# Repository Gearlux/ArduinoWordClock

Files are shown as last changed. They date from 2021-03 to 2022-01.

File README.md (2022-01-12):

# NeoWordClock

I started this project when I first saw the [QLockTwo](https://qlocktwo.com/eu/) word clock in a [shop](https://www.lightpoint.be/) while buying the wonderful [Secto Octo 4240](https://www.sectodesign.fi/pendant-lamps/octo-4240-pendant-lamp) lamp.

My girlfriend was also quite impressed, but the price tag kept me from buying the clock. When home, I decided to build a clock myself. Research on the internet led to some kits:
- [Du kansst mitspielen](https://www.du-kannst-mitspielen.com/p/bausatz-303-universal-version-2-3)
- [build-yours.de](https://build-yours.de/product/wordclock-jupiter/)
- [Leuchtbildshop.de](https://www.leuchtbildshop.net/epages/64015097.sf/de_DE/?ObjectPath=Categories)
- [Bastel Laden](https://bastelladen.wortuhr.de/wortuhr-bausatz-42ger-classic.html)

The goal however was to build my own clock. I will try to describe the process here.

The biggest challenge was the electronics. While there are several [DIY](https://en.wikipedia.org/wiki/Do_it_yourself) instructions available
- [Wordclock](https://www.instructables.com/Wordclock/)
- [ArduinoWordClock](https://www.instructables.com/Arduino-Word-Clock/)
this involved a lot of soldering and wires. 

More research led to the [QlockTwo_DIY](https://github.com/jolau/QlockTwo_DIY) github project.
These seemed the most promising project, but I was confused by the schematics



Not knowing anything about Arduino and electronics, I decided to buy the [ELEGOO UNO R3 Super Starter kit](https://www.elegoo.com/collections/uno-r3-starter-kits/products/elegoo-uno-project-super-starter-kit). Not because it was the best, but it was the cheapest kit which was directly available.

With the [Elegoo tuturial](https://www.elegoo.com/blogs/arduino-projects/elegoo-uno-project-super-starter-kit-tutorial), I managed to get myself a little bit familiar with [Arduino](https://www.arduino.cc/) and it's electronics. 
The journey of the word clock can begin ...

- [Tutorials combined ... and more](prototype/prototype.md)
- [User Interface](userinterface/userinterface.md)
- [Settings](settings/settings.md) stored

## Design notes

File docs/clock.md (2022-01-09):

# Clock mode

When you enter the clock mode, "het is" is displayed in red and blue (or starts blinking if you have a prototype).

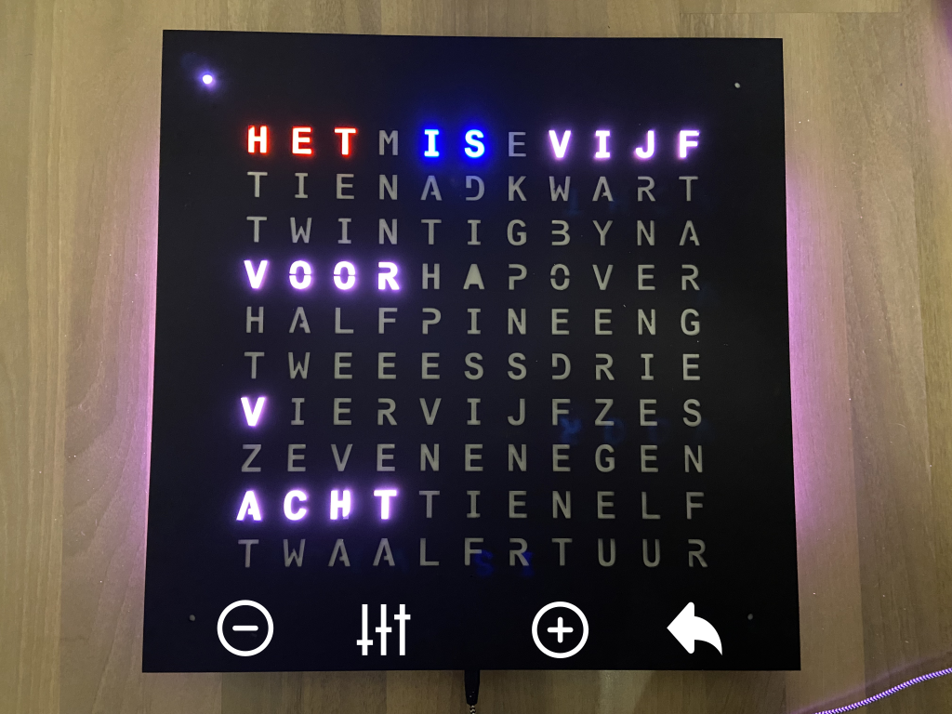
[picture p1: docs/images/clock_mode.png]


Depending on the mode, the hour, the five minutes or the minute dots start blinking.

| | |
| -- | -- |
|  | &bull; Tap to decrease hour/5 minutes/minute dots |
|  | &bull; Tap to cycle through hour/5 minutes/minute dots Auto/High/Low brightness <br/> &bull; Hold to reset seconds |
|  | &bull; Tap to increase hour/5 minutes/minute dots  |
|  | &bull; Hold to return to [main mode](main.md) |

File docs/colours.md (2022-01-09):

# Colour mode

Colour mode looks like this

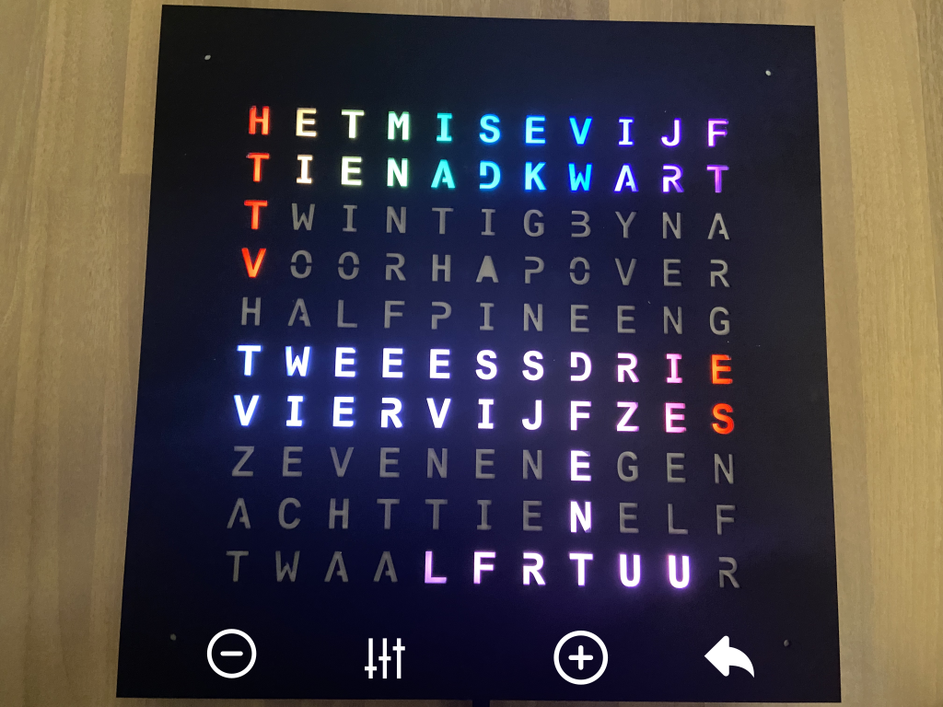
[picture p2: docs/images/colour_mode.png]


You can set the [hue](https://en.wikipedia.org/wiki/Hue) and the [saturation](https://en.wikipedia.org/wiki/HSL_and_HSV) of the leds.
The brightness is controlled in the [brightness mode](brightness.md).

| | |
| -- | -- |
|  | &bull; Tap to decrease hue/saturation |
|  | &bull; Tap to toggle between hue and saturation |
|  | &bull; Tap to increase hue/saturation |
|  | &bull; Hold to return to [main mode](main.md) |

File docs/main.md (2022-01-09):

# Main mode

When booting the clock, all letters will be displayed in rainbow colors. At the bottom of the clock, you find 4 zones to set and configure the clock.

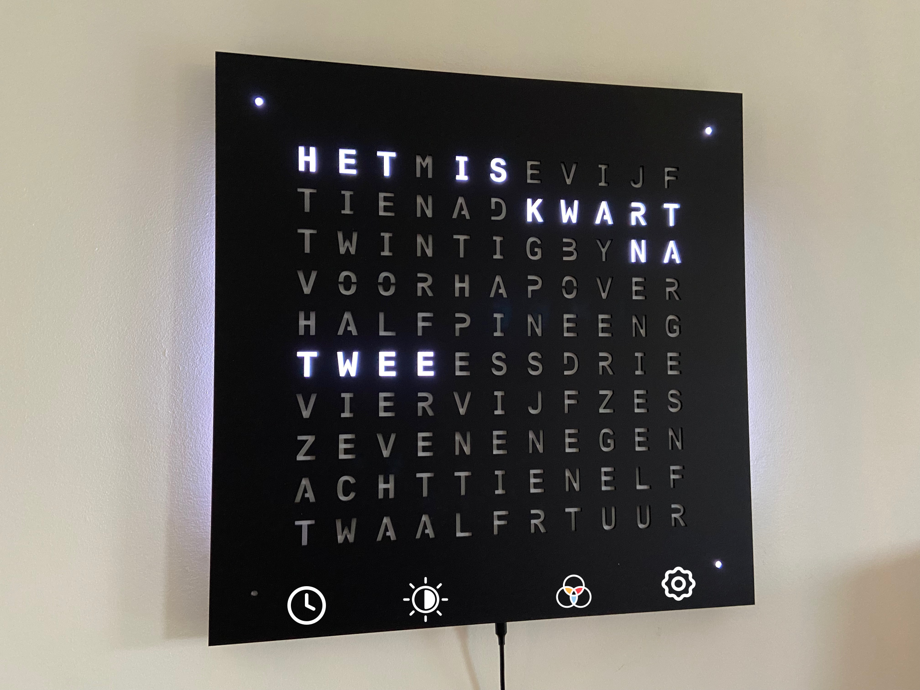
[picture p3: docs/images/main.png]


It is important that you do not touch the capacitive zones at the bottom of the clock when the clock initializes. If the clock behaves weird, unplug the power and repower the clock to reset these capacitive zones.

| | |
| -- | -- |
|  | &bull; Tap to toggle seconds on/off <br/>  &bull; Hold to enter [clock mode](clock.md)  |
|  | &bull; Tap to toggle Auto/High/Low brightness <br/>  &bull; Hold to enter [brightness mode](brightness.md) |
|  | &bull; Tap to cycle colours <br/>  &bull;  Hold to [configure your colour](colours.md)  |
|  | &bull; Tap to see a surprise <br/>  &bull; Hold to [configure the clock](settings.md)  |

## Startup Screen

If you boot the clock, rainbow colors appear

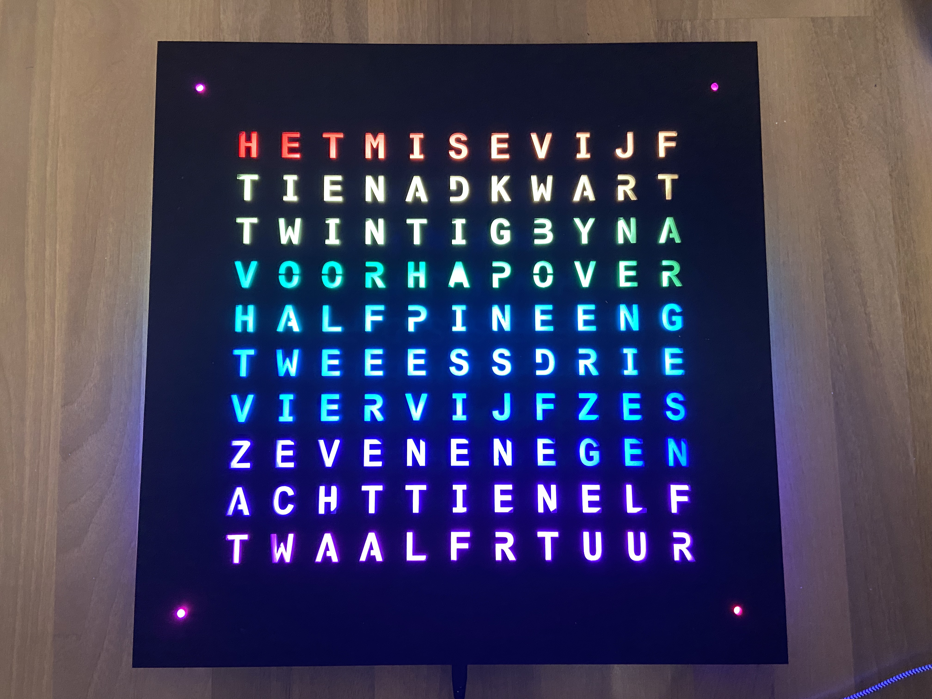
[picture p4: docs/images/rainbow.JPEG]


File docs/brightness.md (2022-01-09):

# Brightness mode

When you enter brightness mode, you see the following screen

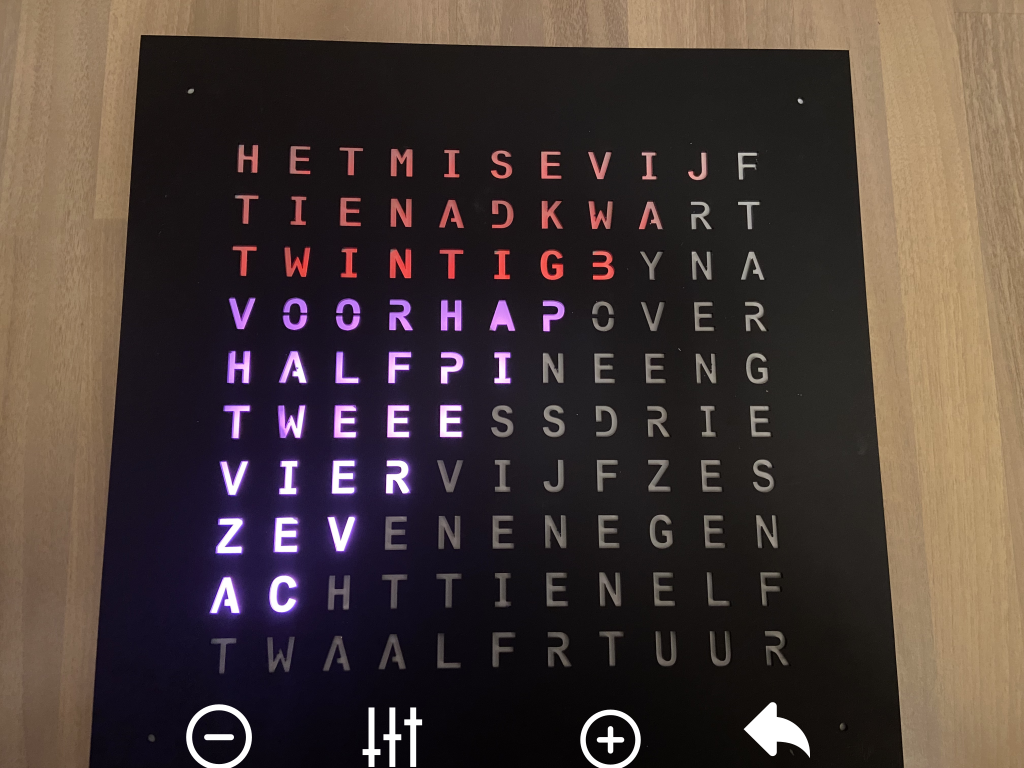
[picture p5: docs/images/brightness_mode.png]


The top row represents the minimum brightness, the bottom row represents the maximum brightness. The active row will blink.

| | |
| -- | -- |
|  | &bull; Tap to decrease minimum/maximum brightness |
|  | &bull; Tap to toggle between minimum and maximum brightness |
|  | &bull; Tap to increase minimum/maximum brightness |
|  | &bull; Hold to return to [main mode](main.md) |

## Automatic brightness

In automatic brightness mode (see [main mode](main.md)) the brightness is determined by the amount of light that is measured by the light sensor next to the power supply.

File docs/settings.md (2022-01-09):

# Settings mode

In settings mode, the clock is temporarily set to 12:20 or 12:40.

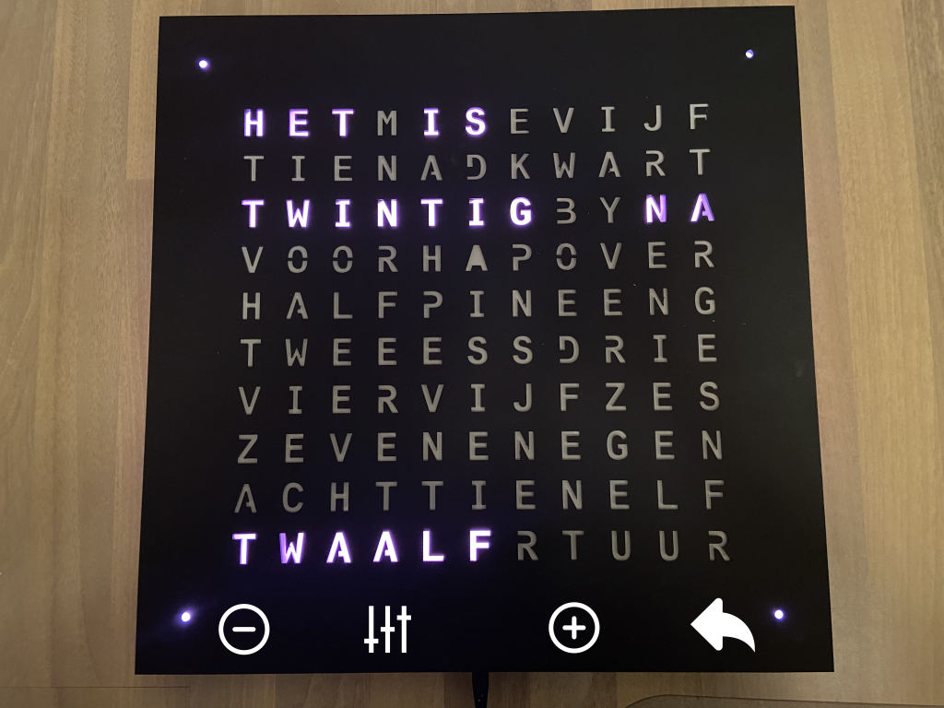
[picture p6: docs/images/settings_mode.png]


| | |
| -- | -- |
|  | &bull; Tap to toggle the display of "Het is" <br/> &bull; Hold to toggle the display of the minute dots |
|  | &bull; Tap to toggle between "over" and "na" <br/> &bull; Hold to toggle between "twintig over/na/voor" and "tien voor/over/na half" |
|  | &bull; Tap to switch the backlight on or off <br/> &bull; Tap to switch between normal or faded transition |
|  | &bull; Hold to return to [main mode](main.md) |

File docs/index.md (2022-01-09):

# NeoWordClock

The 50x50cm NeoWordClock is mounted on the wall like a picture and is currently only available in Dutch.

<center>
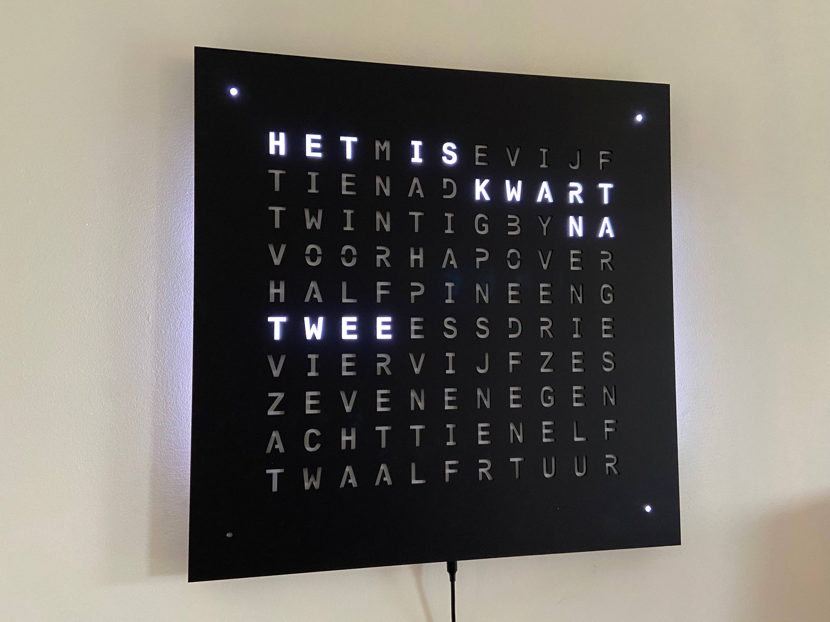
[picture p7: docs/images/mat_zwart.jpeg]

</center>

The dots show the minutes: 'Het is 18 na twee'.

## Unique Features

### Coloured Letters

It is possible to change the colour of the letters and set the mood of the clock.

<center>
<video width="320" height="240" controls autoplay loop>
  <source src="videos/NeoWordClock.mp4" type="video/mp4">
</video>
</center>

### Backlight

The backlight of the clock creates the correct ambiance in your room.

<center>
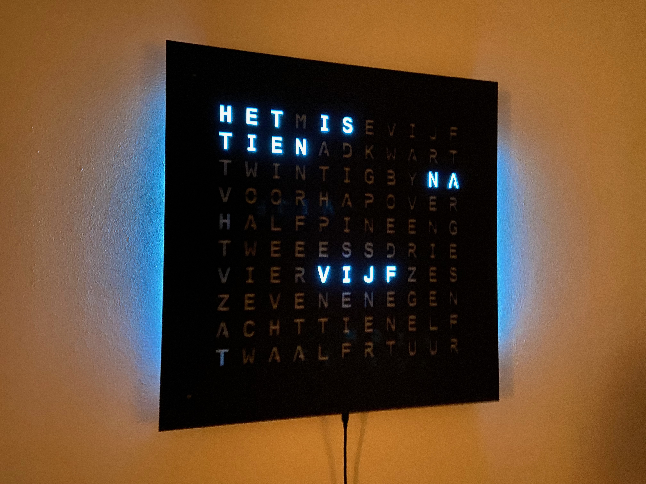
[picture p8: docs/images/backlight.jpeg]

</center>

### Fader

The clock can fade from one hour to another.

<center>
<video width="320" height="240" controls autoplay loop>
  <source src="videos/fading.mp4" type="video/mp4">
</video>
</center>
### Seconds

Seconds can be displayed as a moving letter. This turns the clock into the ultimate device in times where every second matters.

<center>
<video width="320" height="240" controls autoplay loop>
  <source src="videos/Seconds.mp4" type="video/mp4">
</video>
</center>

### Dialects

The clock can be configured for some dutch dialects. You can switch between 'over' and 'na'. 'Twintig na' of 'tien voor half' are other possibilities.

## Manual

Please consult the [online manual](main.md).

## Colors

Currently only available in acrylic matt black.

Other colours are available and a variety of wooden fronts is also possible.

### Disclaimer

This is a hobby project. The clock is not commercially available.
If something in the repository violates a license, let me know so I can remove it or add the correct license or reference.

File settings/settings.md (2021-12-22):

# Settings

Having defined the [user interface](userinterface/userinterface.md), we want to store the settings after a power failure.

Looking closely at the [code](userinterface/userinterface.ino), the following variables need to be stored:
- color_index (byte)
- it_is (bit)
- auto_high (byte)
- auto_low (byte)
- current_brightness (byte)

Because the ROM only has a minimal amount of writes, we are only going to write the settings after a timeout.

Based on the technical specifications of the DS1307 clock module in the kit, these values can be written to addresses 0x08 to 0x0C. The code read and write the registers is stolen from the [DS3231](https://github.com/rodan/ds3231) library.

```
void store_settings() 
{
  Serial.println("store_settings");
  writeRegister8(0x08, (byte)color_index);
  writeRegister8(0x09, (byte)it_is);
  writeRegister8(0x0A, (byte)auto_high);
  writeRegister8(0x0B, (byte)auto_low);

  int bm = max(0, current_brightness);
  writeRegister8(0x0C, (byte)bm);
  
}

void restore_settings()
{
  Serial.println("restore_settings");
  color_index = min(nr_led_colors, readRegister8(0x08));
  it_is = readRegister8(0x09);
  auto_high = min(15, readRegister8(0x0A));
  auto_low = min(auto_high-1, readRegister8(0x0B));
  byte bmb = readRegister8(0x0C);
  if (bmb == 0) 
    current_brightness = automatic;
  else
    current_brightness = bmb;
}
```

Because the restore_settings behaves a little strange when reading uninitialized values, a [default settings](default_settings/default_settings.ino) program is provided to initialize the clock and the settings to appropriate default values.

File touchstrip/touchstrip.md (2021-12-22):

My first idea for a three button config is here

| Button | Event | Command |
|---|---|---|
| 1 | Clicked | show_seconds |
| | LongPressed | clock_mode |
| 2 | Clicked | toggle_brightness |
| | LongPressed | brightness_mode |
| 3 | Clicked | toggle_rgb |
| | LongPressed | rgb_mode |
| 4 | Clicked | Don't Buy Happpiness Surf |
| | LongPressed | config_mode |

For the *clock_mode*

| Button | Event | Command |
|---|---|---|
| 1 | Clicked | decrease |
| 2 | Clicked | toggle hour/5min/min |
| | LongPressed | reset_seconds |
| 3 | Clicked | increase |
| 4 | LongPressed | main_mode |
| (Inactive) | 60s | main_mode |

In clock_mode, the seconds will go around the outer circle of the clock.

For the *brightness mode*

| Button | Event | Command |
|---|---|---|
| 1 | Clicked | brightness_down |
| 2 | Clicked | toggle_brightness_input |
| 3 | Clicked | brightness_up |
| 4 | LongPressed | main_mode |
| (Inactive) | 60s | main_mode |

For the *rgb mode*

| Button | Event | Command |
|---|---|---|
| 1 | Clicked | hue_sat_up |
| 2 | Clicked | toggle_hue_sat |
| 3 | Clicked | hue_sat_down |
| 4 | LongPressed | main_mode |
| (Inactive) | 60s | main_mode |

For the *config mode*

| Button | Event | Command |
|---|---|---|
| 1 | Clicked | toggle_it_is |
| | LongPressed | toggle_twenty |
| 2 | Clicked | toggle_over |
| | LongPressed | toggle_dot |
| 3 | Clicked | toggle_backlight |
| | LongPressed | toggle_barseconds |
| 4 | LongPressed | main_mode |
| (Inactive) | 60s | main_mode |

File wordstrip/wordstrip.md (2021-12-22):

My first idea for a three button config is here

| Button | Event | Command |
|---|---|---|
| 1 | Clicked | show_seconds |
| | LongPressed | clock_mode |
| 2 | Clicked | toggle_brightness |
| | LongPressed | brightness_mode |
| 3 | Clicked | toggle_rgb |
| | LongPressed | config_mode |

For the *clock_mode*

| Button | Event | Command |
|---|---|---|
| 1 | Clicked | increase_hour |
| | LongPressed | decrease_hour |
| 2 | Clicked | increase_5min |
| | LongPressed | decrease_5min |
| 3 | Clicked | increase_1min |
| | LongPressed | decrease_1min |
| (Inactive) | 60s | main_mode |

In clock_mode, the seconds will go around the outer circle of the clock.

For the *brightness mode*

| Button | Event | Command |
|---|---|---|
| 1 | Clicked | brightness_down |
| 2 | Clicked | toggle_brightness_input |
| | LongPressed | main_mode |
| 3 | Clicked | brightness_up |
| (Inactive) | 60s | main_mode |

For the *config mode*

| Button | Event | Command |
|---|---|---|
| 1 | Clicked | toggle_it_is |
| | LongPressed | toggle_twenty |
| 2 | Clicked | toggle_over |
| | LongPressed | toggle_dot |
| 3 | Clicked | toggle_backlight |
| | LongPressed | main_mode |
| (Inactive) | 60s | main_mode |

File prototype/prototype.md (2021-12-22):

# Prototype

The first protoype I have built was based on the following lessons of the [ELEGOO UNO R3 Super Starter kit](https://www.elegoo.com/collections/uno-r3-starter-kits/products/elegoo-uno-project-super-starter-kit):
- Lesson 0: Installing IDE
- Lesson 1: Add Libraries and Open Serial Monitor
- Lesson 2: Blink
- Lesson 4: RGB LED
- Lesson 5: Digital Inputs
- Lesson 19: Real Time Clock Module
- Lesson 22: LCD Display
- Lesson 23: Thermometer
- Lesson 26: Photocell

with the addition of the [LiquidCrystal_74HC595](https://github.com/matmunk/LiquidCrystal_74HC595) and the [AceButton](https://github.com/bxparks/AceButton) libraries.
This LiquidCrystal_74HC595 library was needed because there were not enough pins to continue the prototype.

I am not proud of the code in the prototype, but is shows that the application is on the right track.
Here are some design decisions:
- 4 buttons based on the original [QlockTwo](https://qlocktwo.com/eu/qlocktwo-classic)
- Temperature sensor based on [Word Clock - Youtube](https://www.youtube.com/watch?v=yctfqg6UF1c)
- Ambient light sensor 
- RGB Led

I will probably ditch the temperature sensor, because it's a clock not a thermometer, and I will try to reduce the number of buttons to 3 while keeping the user interface intuitive.

I recreated all tutorials in the [Arduino IDE](https://www.arduino.cc/en/software). Since I missed code completion, I will be looking into something better for the [user interface design](../userinterface/userinterface.md).

The images look quite impressive (my opinion)

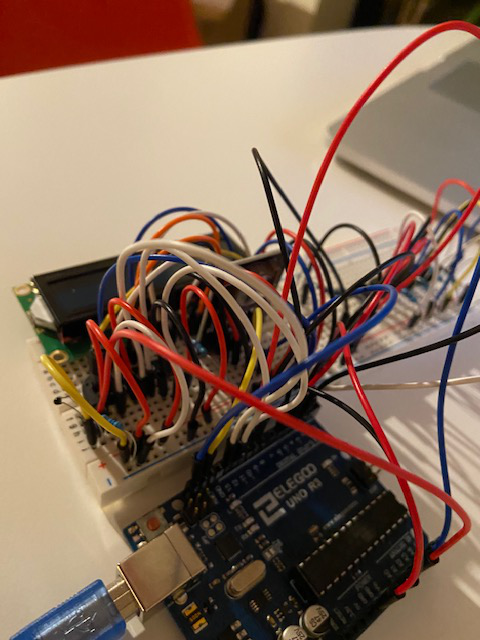
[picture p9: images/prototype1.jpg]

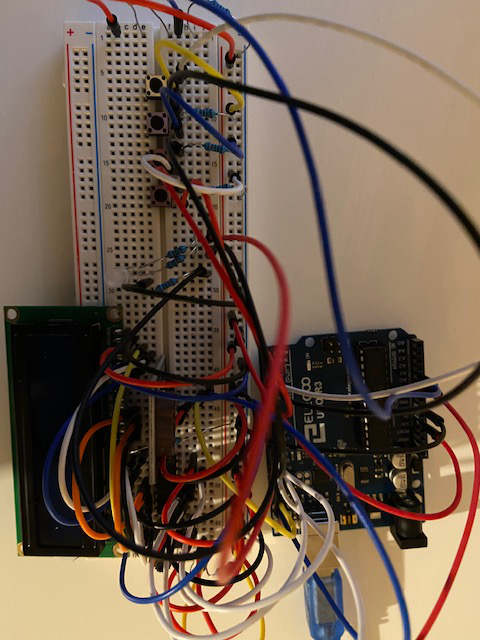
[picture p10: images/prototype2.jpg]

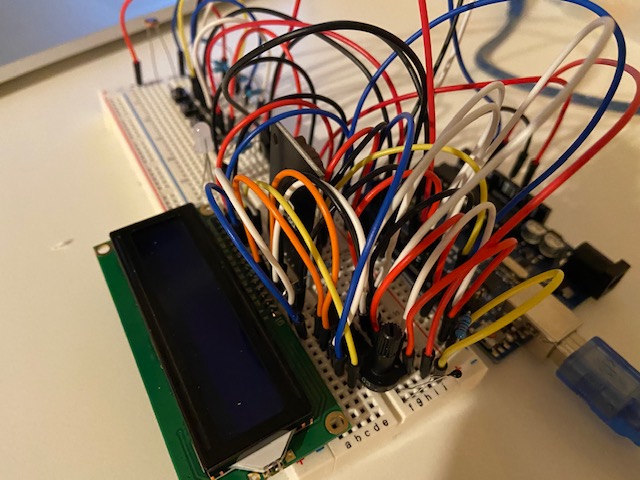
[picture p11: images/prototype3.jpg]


so I decided to also provide the schematics. Other projects are already using [Fritzing](https://fritzing.org/), but the site "forced" me to pay for the software. Fortunately, you can sign up for an account first, after which you can download the program for free (thanks [Fabian](https://blog.spaps.de/download-fritzing-for-free-with-out-donation/)).

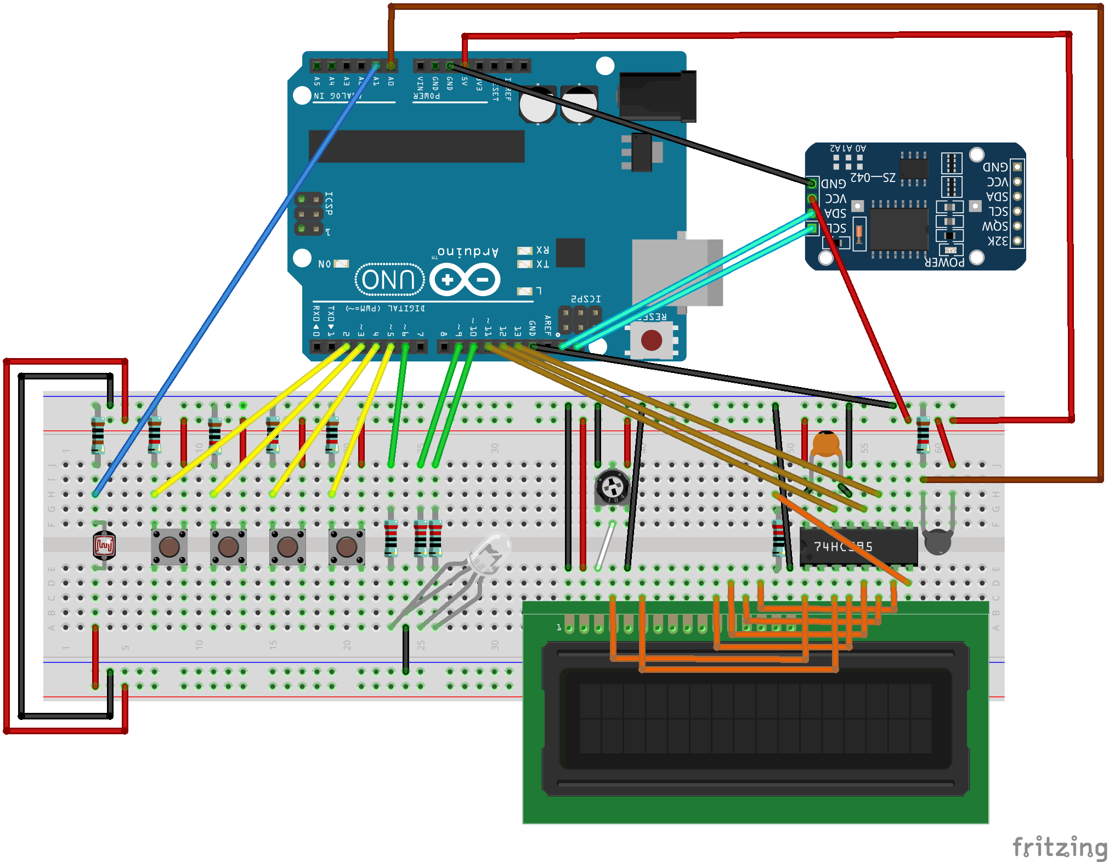
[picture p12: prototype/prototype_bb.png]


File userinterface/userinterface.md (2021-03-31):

# User Interface

## Visual Studio Code

After building the prototype, it's time to get serious about Arduino development.
Let's start by setting up [Visual Studio Code](https://github.com/microsoft/vscode-arduino)

<div class="panel panel-warning">
**Warning**
{: .panel-heading}
<div class="panel-body">

Don't use the Windows Store's version of the Arduino IDE.

</div>
</div>

I had some troubles configuring the Arduino tools, most likely because I installed the Windows Store's version and already installed the extension. I had to manually add the paths to the Visual Studio Code. The "Board Type" can be configured with "Ctrl+Shift+P > Arduino: Change board type".
I also changed the default baud rate to 9600 and did not go for the cli (yet).

Changing ino files was a little bit difficult. It seems that with each workspace, only one ino file is associated.
The easiest way to change your main ino file is editing the .vscode/arduino.json file, deleting the "sketch" entry and manually choosing the sketch file when clicking "verify" or "upload".

## Keep it simple

Let's simplify the board first and remove the thermometer - a clock is not a thermometer - and remove one of the buttons.

My first idea for a three button config is here

| Button | Event | Command |
|---|---|---|
| 1 | Clicked | show_seconds |
| | LongPressed | clock_mode |
| 2 | Clicked | toggle_brightness |
| | LongPressed | brightness_mode |
| 3 | Clicked | toggle_rgb |
| | LongPressed | toggle_itis |

For the *clock_mode*

| Button | Event | Command |
|---|---|---|
| 1 | Clicked | increase_hour |
| | LongPressed | decrease_hour |
| 2 | Clicked | increase_5min |
| | LongPressed | decrease_5min |
| 3 | Clicked | increase_1min |
| | LongPressed | decrease_1min |
| (Inactive) | 60s | main_mode |

In clock_mode, the seconds will go around the outer circle of the clock.

For the *brightness mode*

| Button | Event | Command |
|---|---|---|
| 1 | Clicked | brightness_down |
| 2 | Clicked | toggle_brightness_input |
| | LongPressed | main_mode |
| 3 | Clicked | brightness_up |
| (Inactive) | 60s | main_mode |

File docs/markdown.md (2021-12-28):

## NeoWordClock

You can use the [editor on GitHub](https://github.com/Gearlux/NeoWordClock/edit/main/docs/index.md) to maintain and preview the content for your website in Markdown files.

Whenever you commit to this repository, GitHub Pages will run [Jekyll](https://jekyllrb.com/) to rebuild the pages in your site, from the content in your Markdown files.

### Markdown

Markdown is a lightweight and easy-to-use syntax for styling your writing. It includes conventions for

```markdown
Syntax highlighted code block

# Header 1
## Header 2
### Header 3

- Bulleted
- List

1. Numbered
2. List

**Bold** and _Italic_ and `Code` text

[Link](url) and ![Image](src)
```

For more details see [Basic writing and formatting syntax](https://docs.github.com/en/github/writing-on-github/getting-started-with-writing-and-formatting-on-github/basic-writing-and-formatting-syntax).

### Jekyll Themes

Your Pages site will use the layout and styles from the Jekyll theme you have selected in your [repository settings](https://github.com/Gearlux/NeoWordClock/settings/pages). The name of this theme is saved in the Jekyll `_config.yml` configuration file.

### Support or Contact

Having trouble with Pages? Check out our [documentation](https://docs.github.com/categories/github-pages-basics/) or [contact support](https://support.github.com/contact) and we’ll help you sort it out.

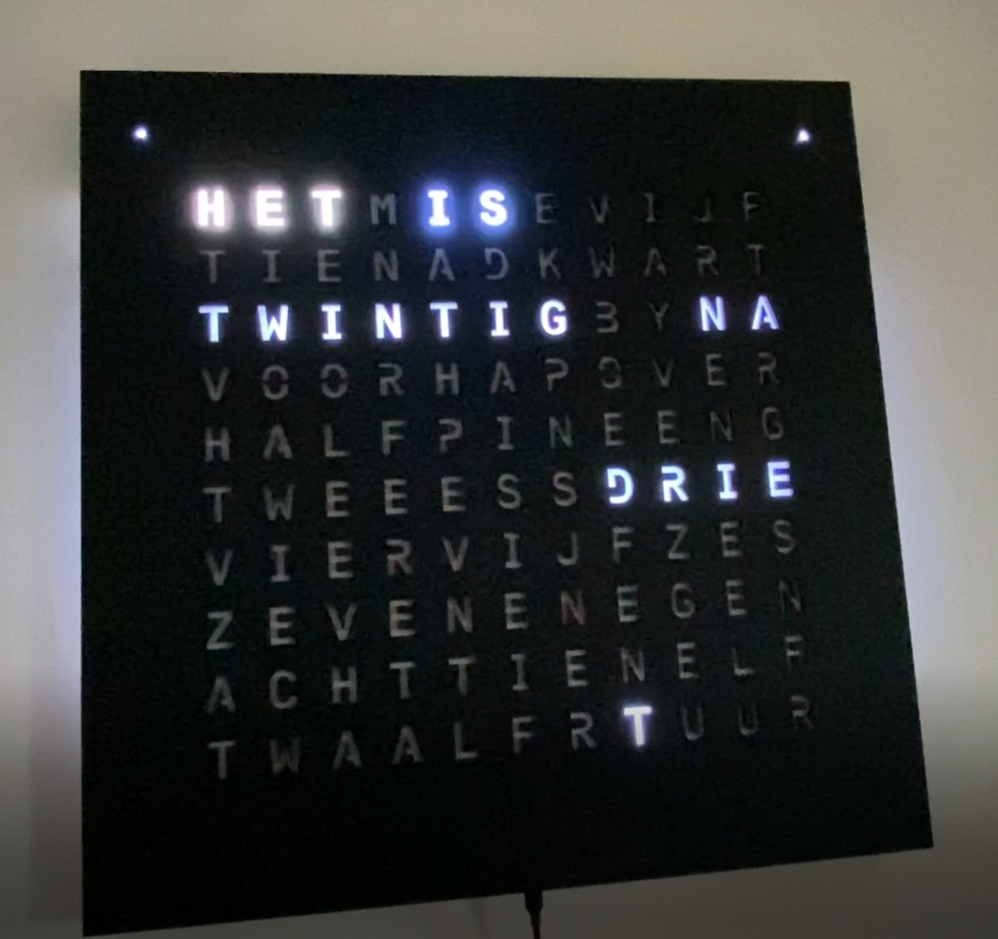
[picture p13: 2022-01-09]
docs/images/clock.png

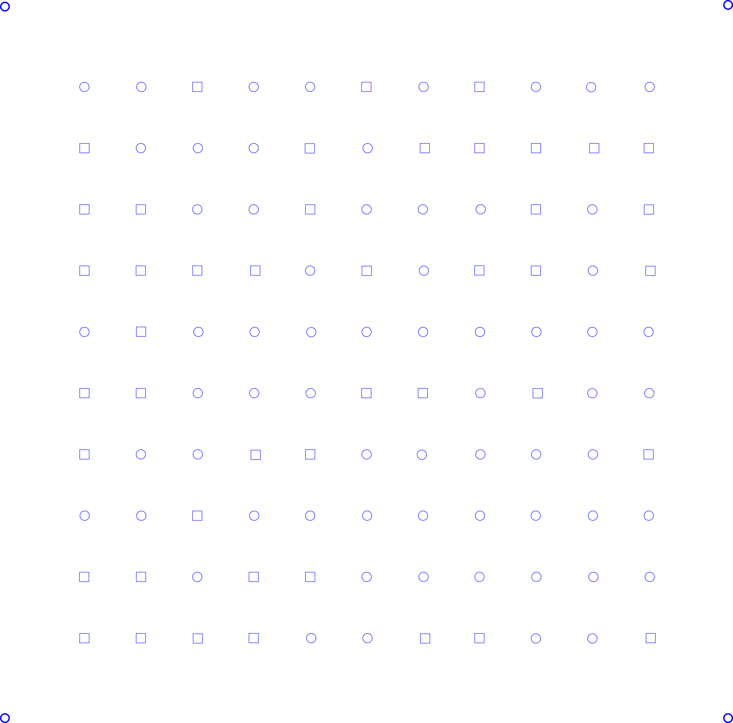
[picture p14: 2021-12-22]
images/centers.png

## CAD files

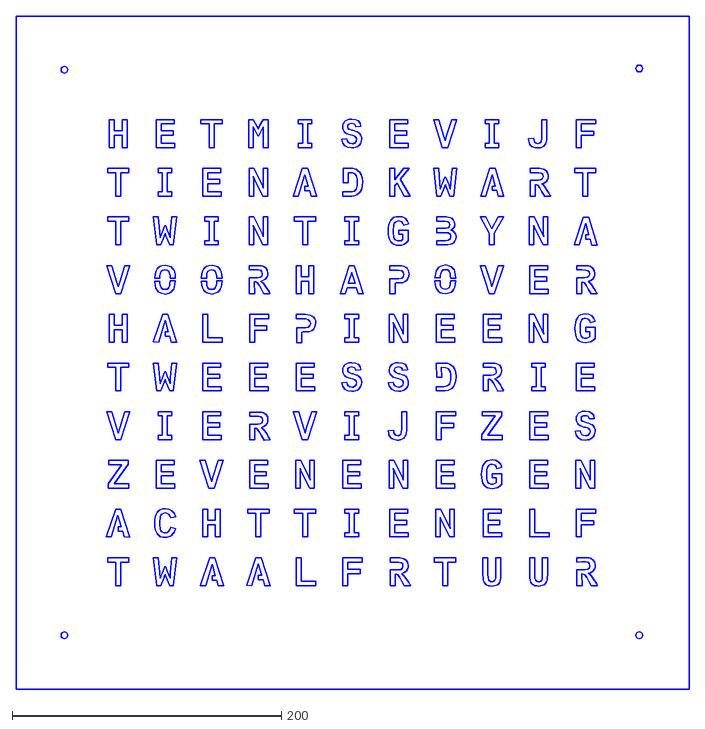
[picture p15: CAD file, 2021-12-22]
images/Qlocktwo_blank_laser_v3.dxf
499.9 x 499.9

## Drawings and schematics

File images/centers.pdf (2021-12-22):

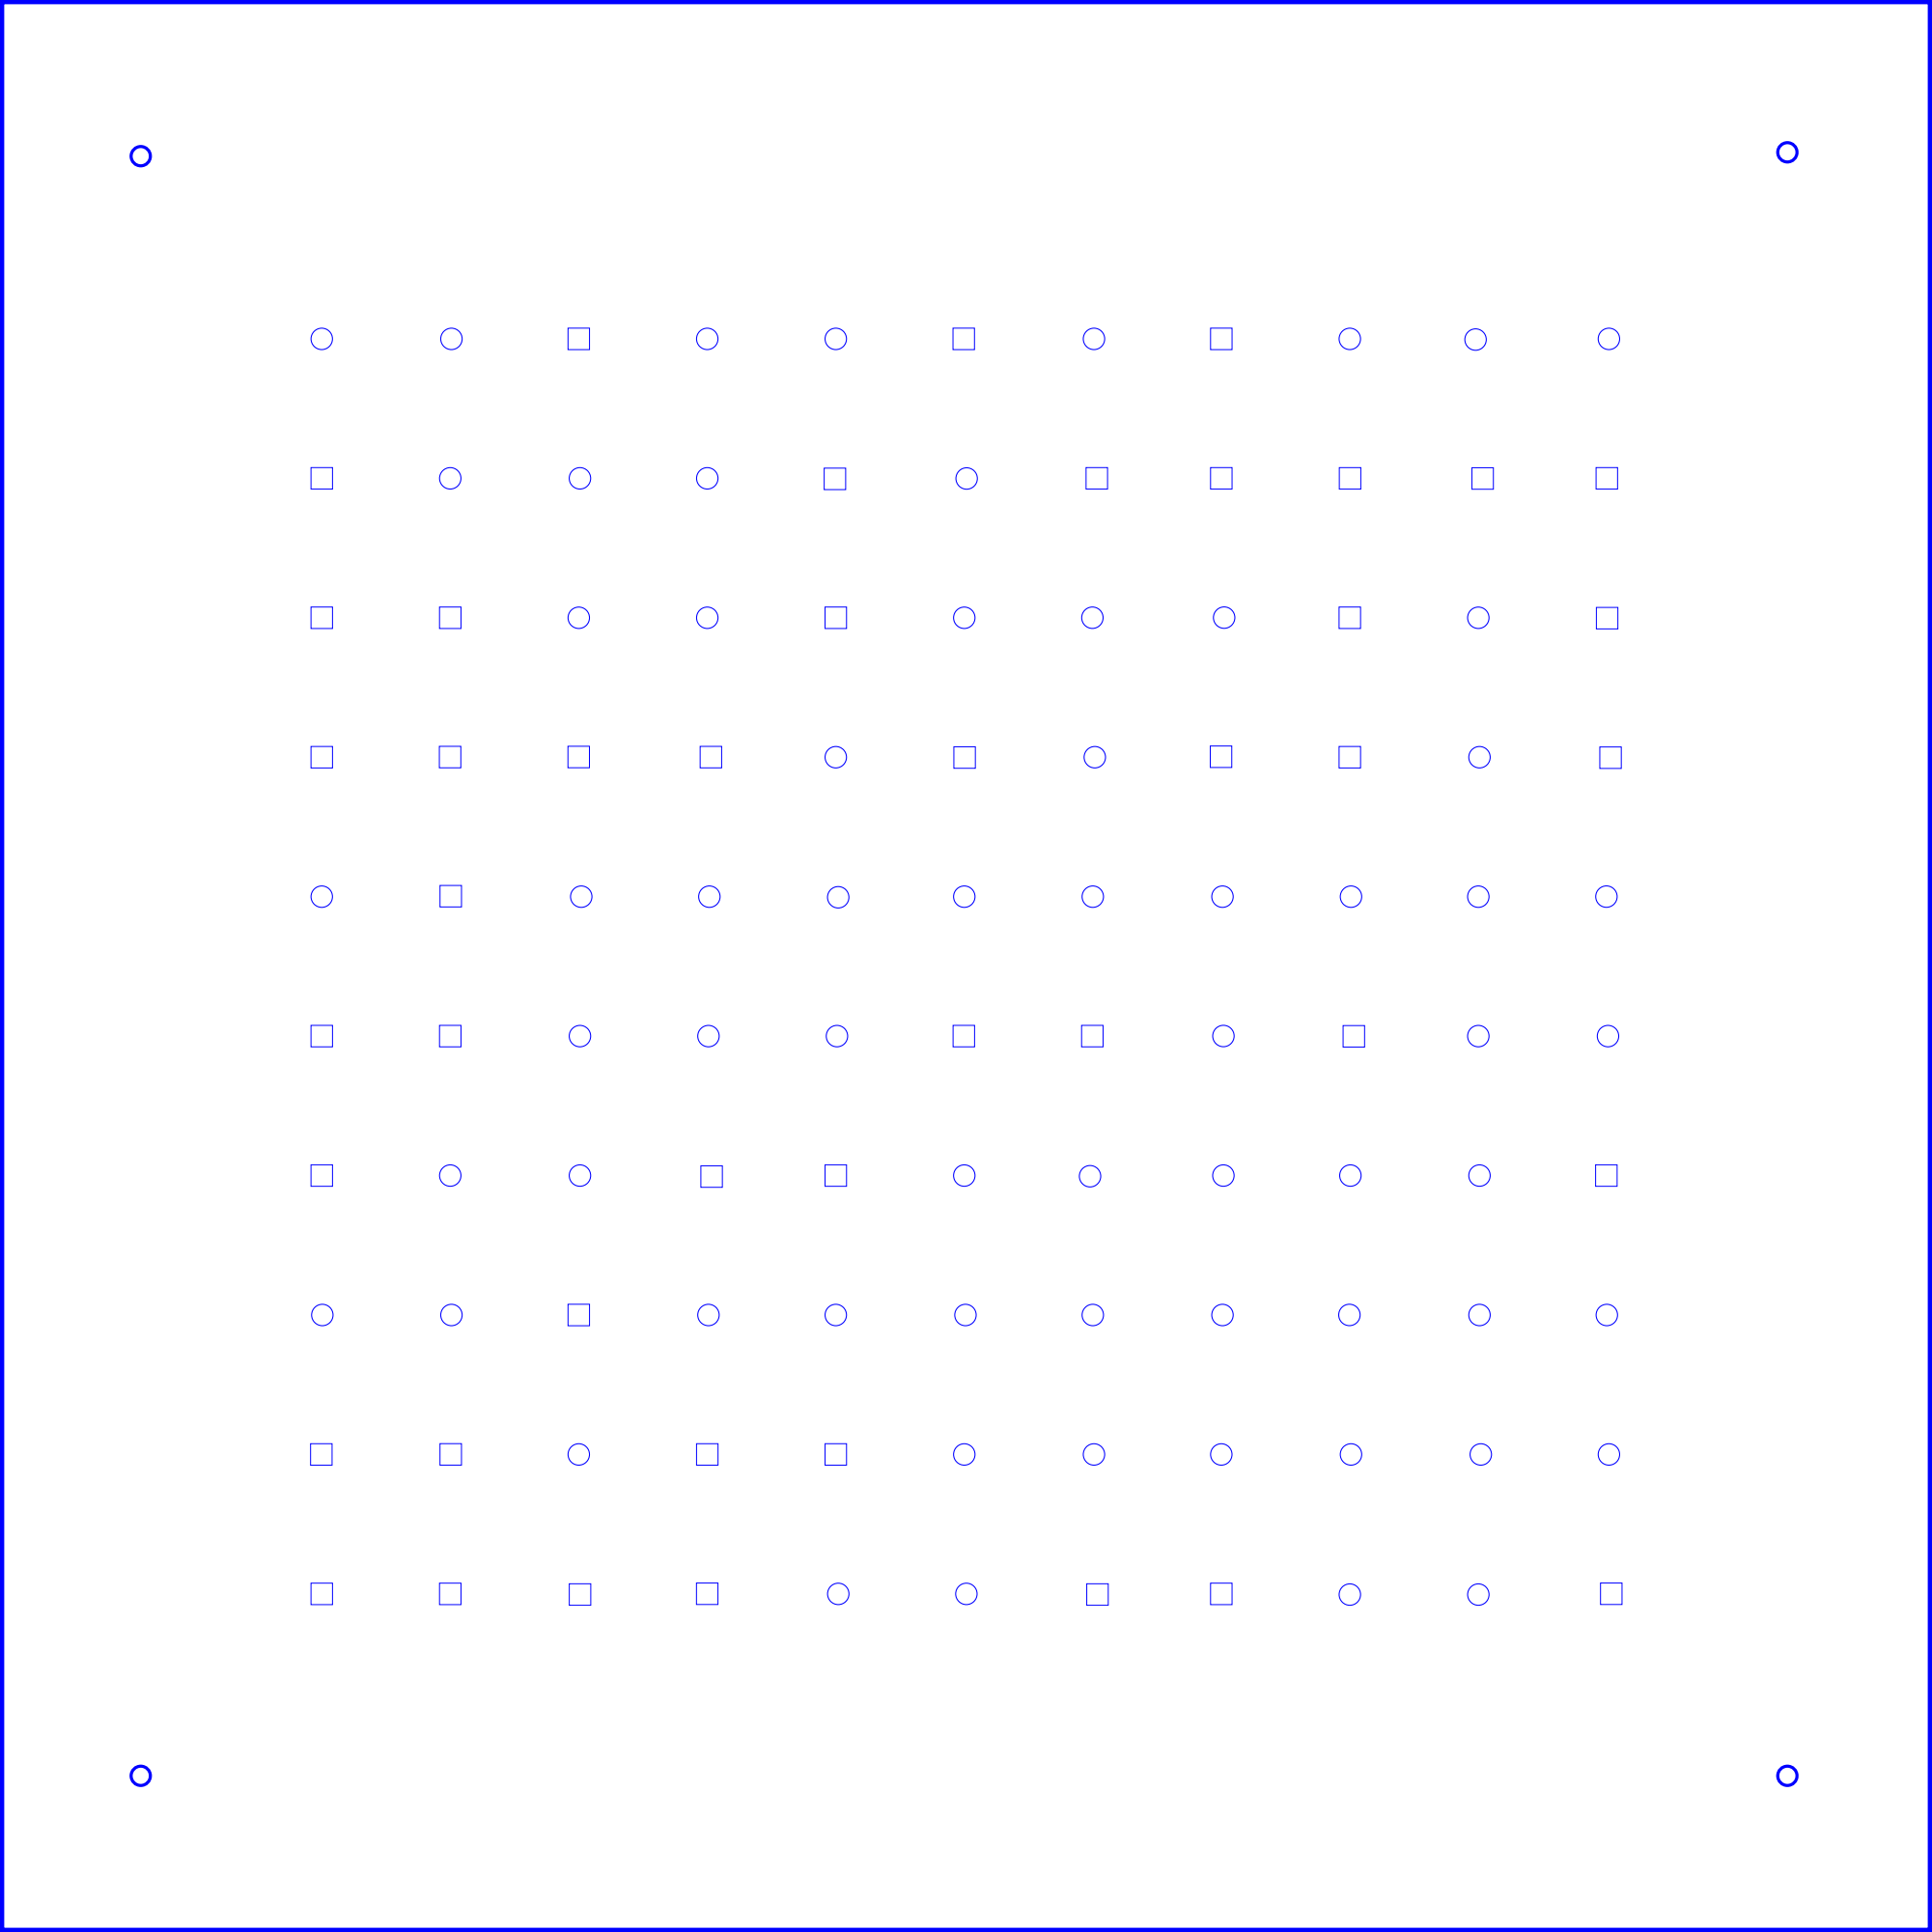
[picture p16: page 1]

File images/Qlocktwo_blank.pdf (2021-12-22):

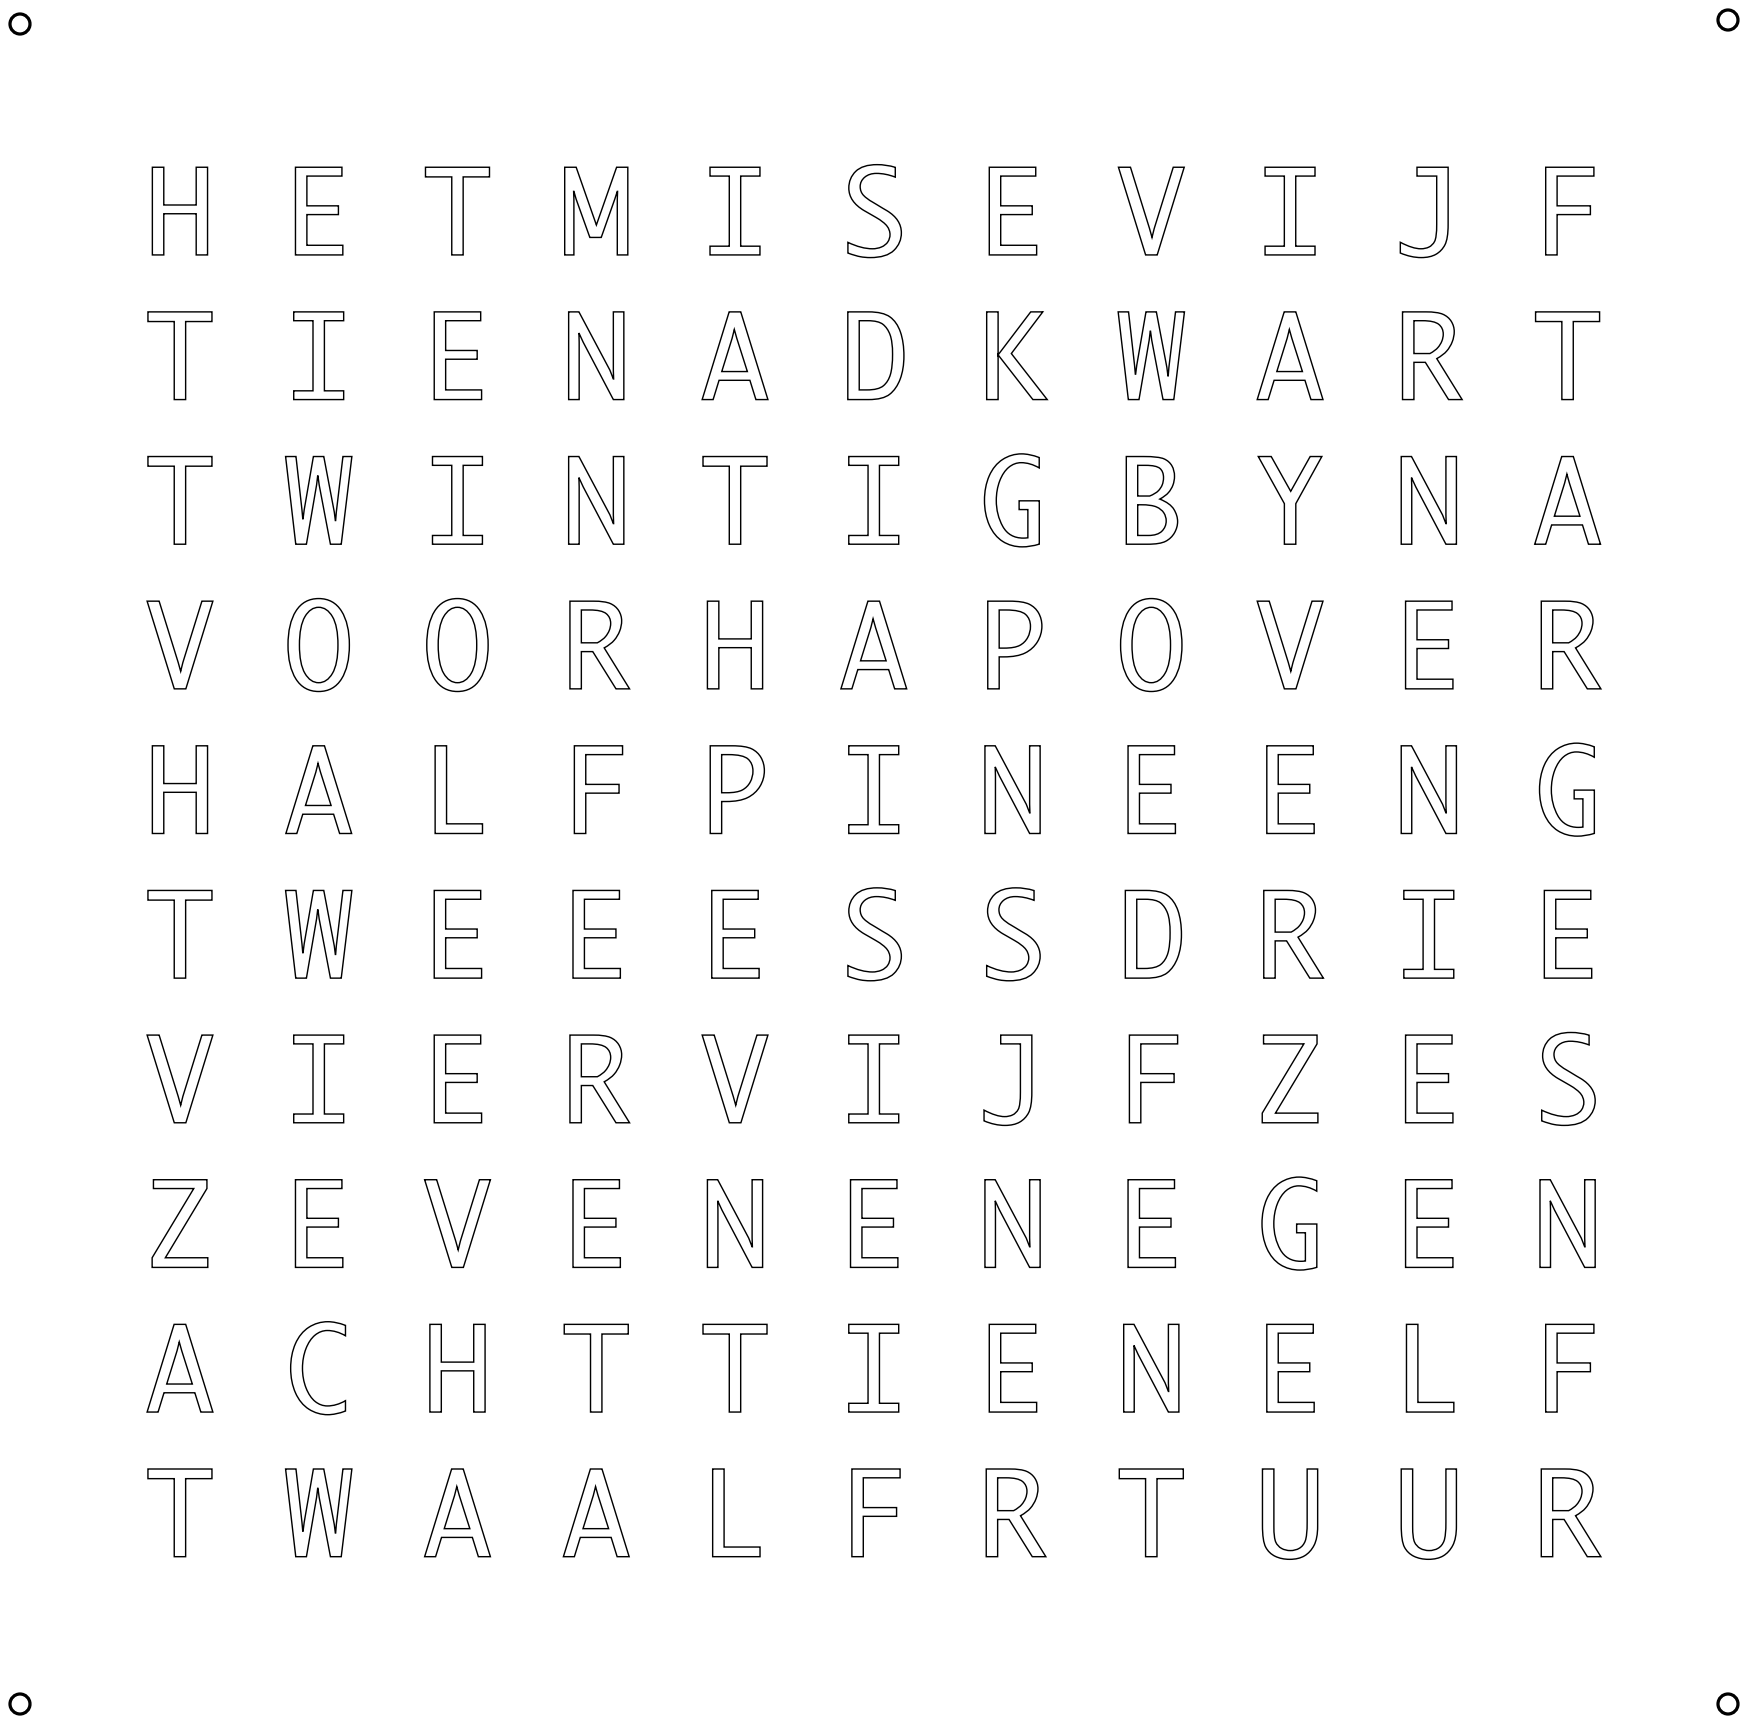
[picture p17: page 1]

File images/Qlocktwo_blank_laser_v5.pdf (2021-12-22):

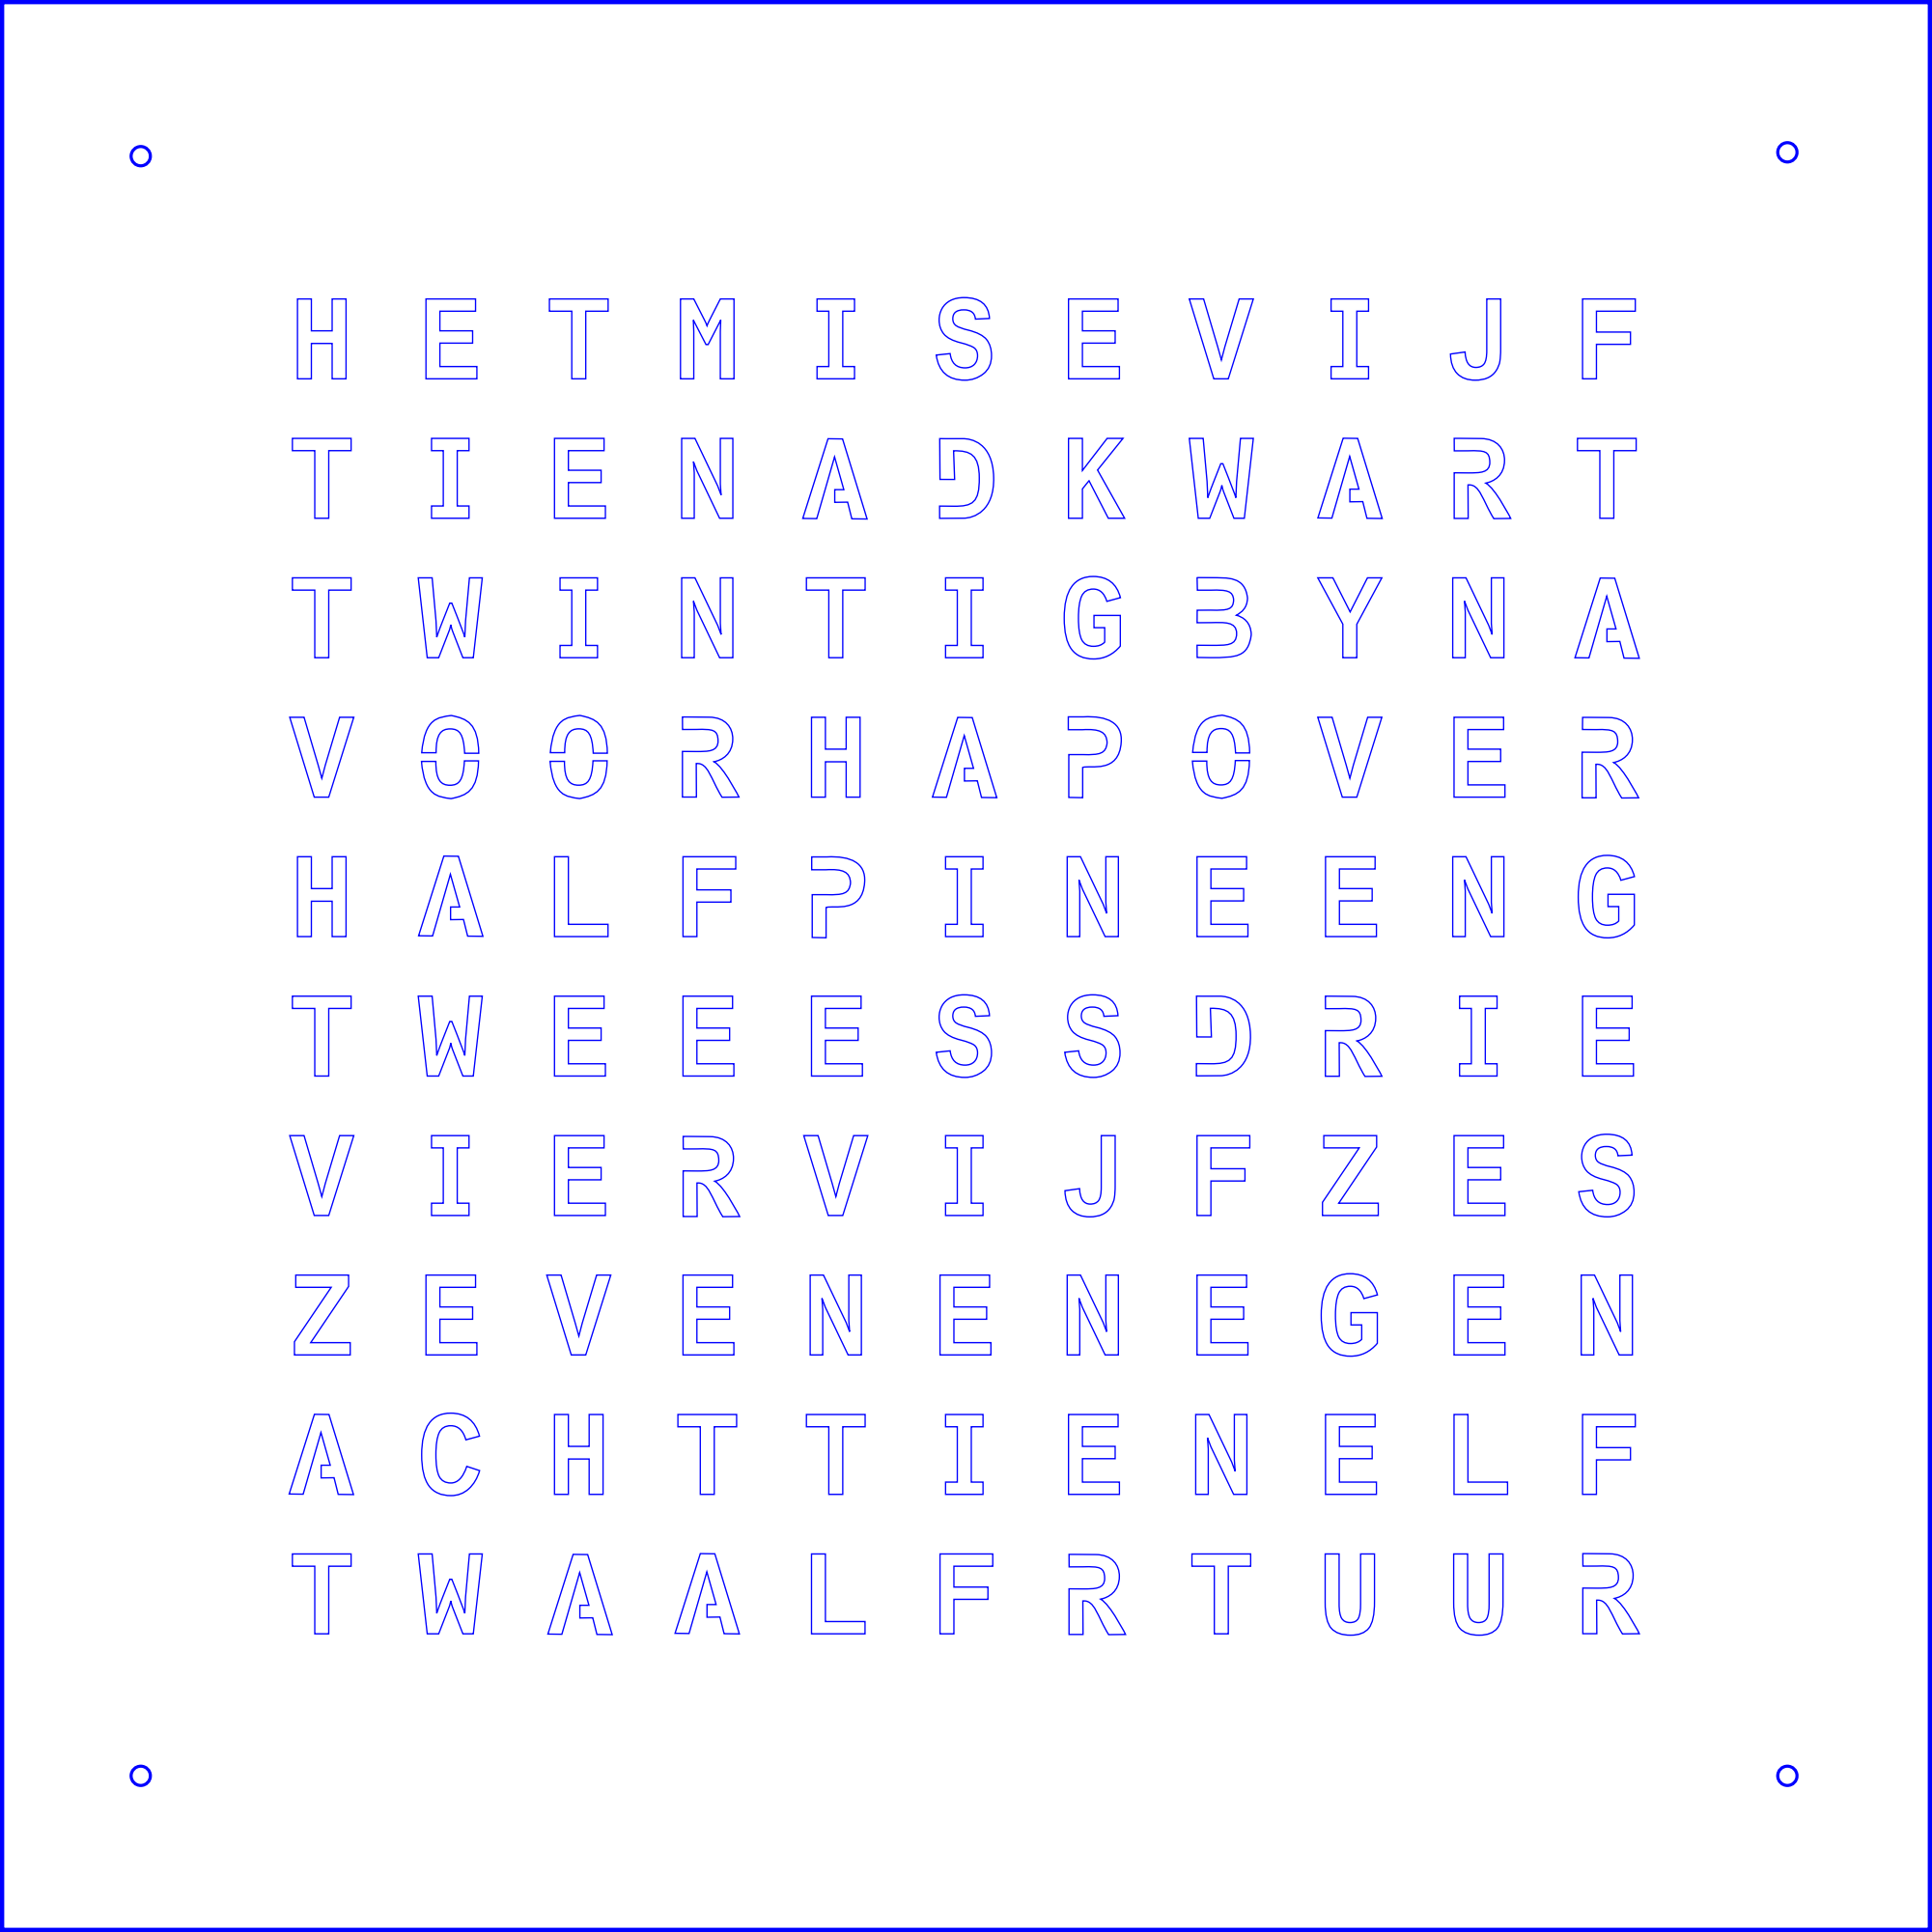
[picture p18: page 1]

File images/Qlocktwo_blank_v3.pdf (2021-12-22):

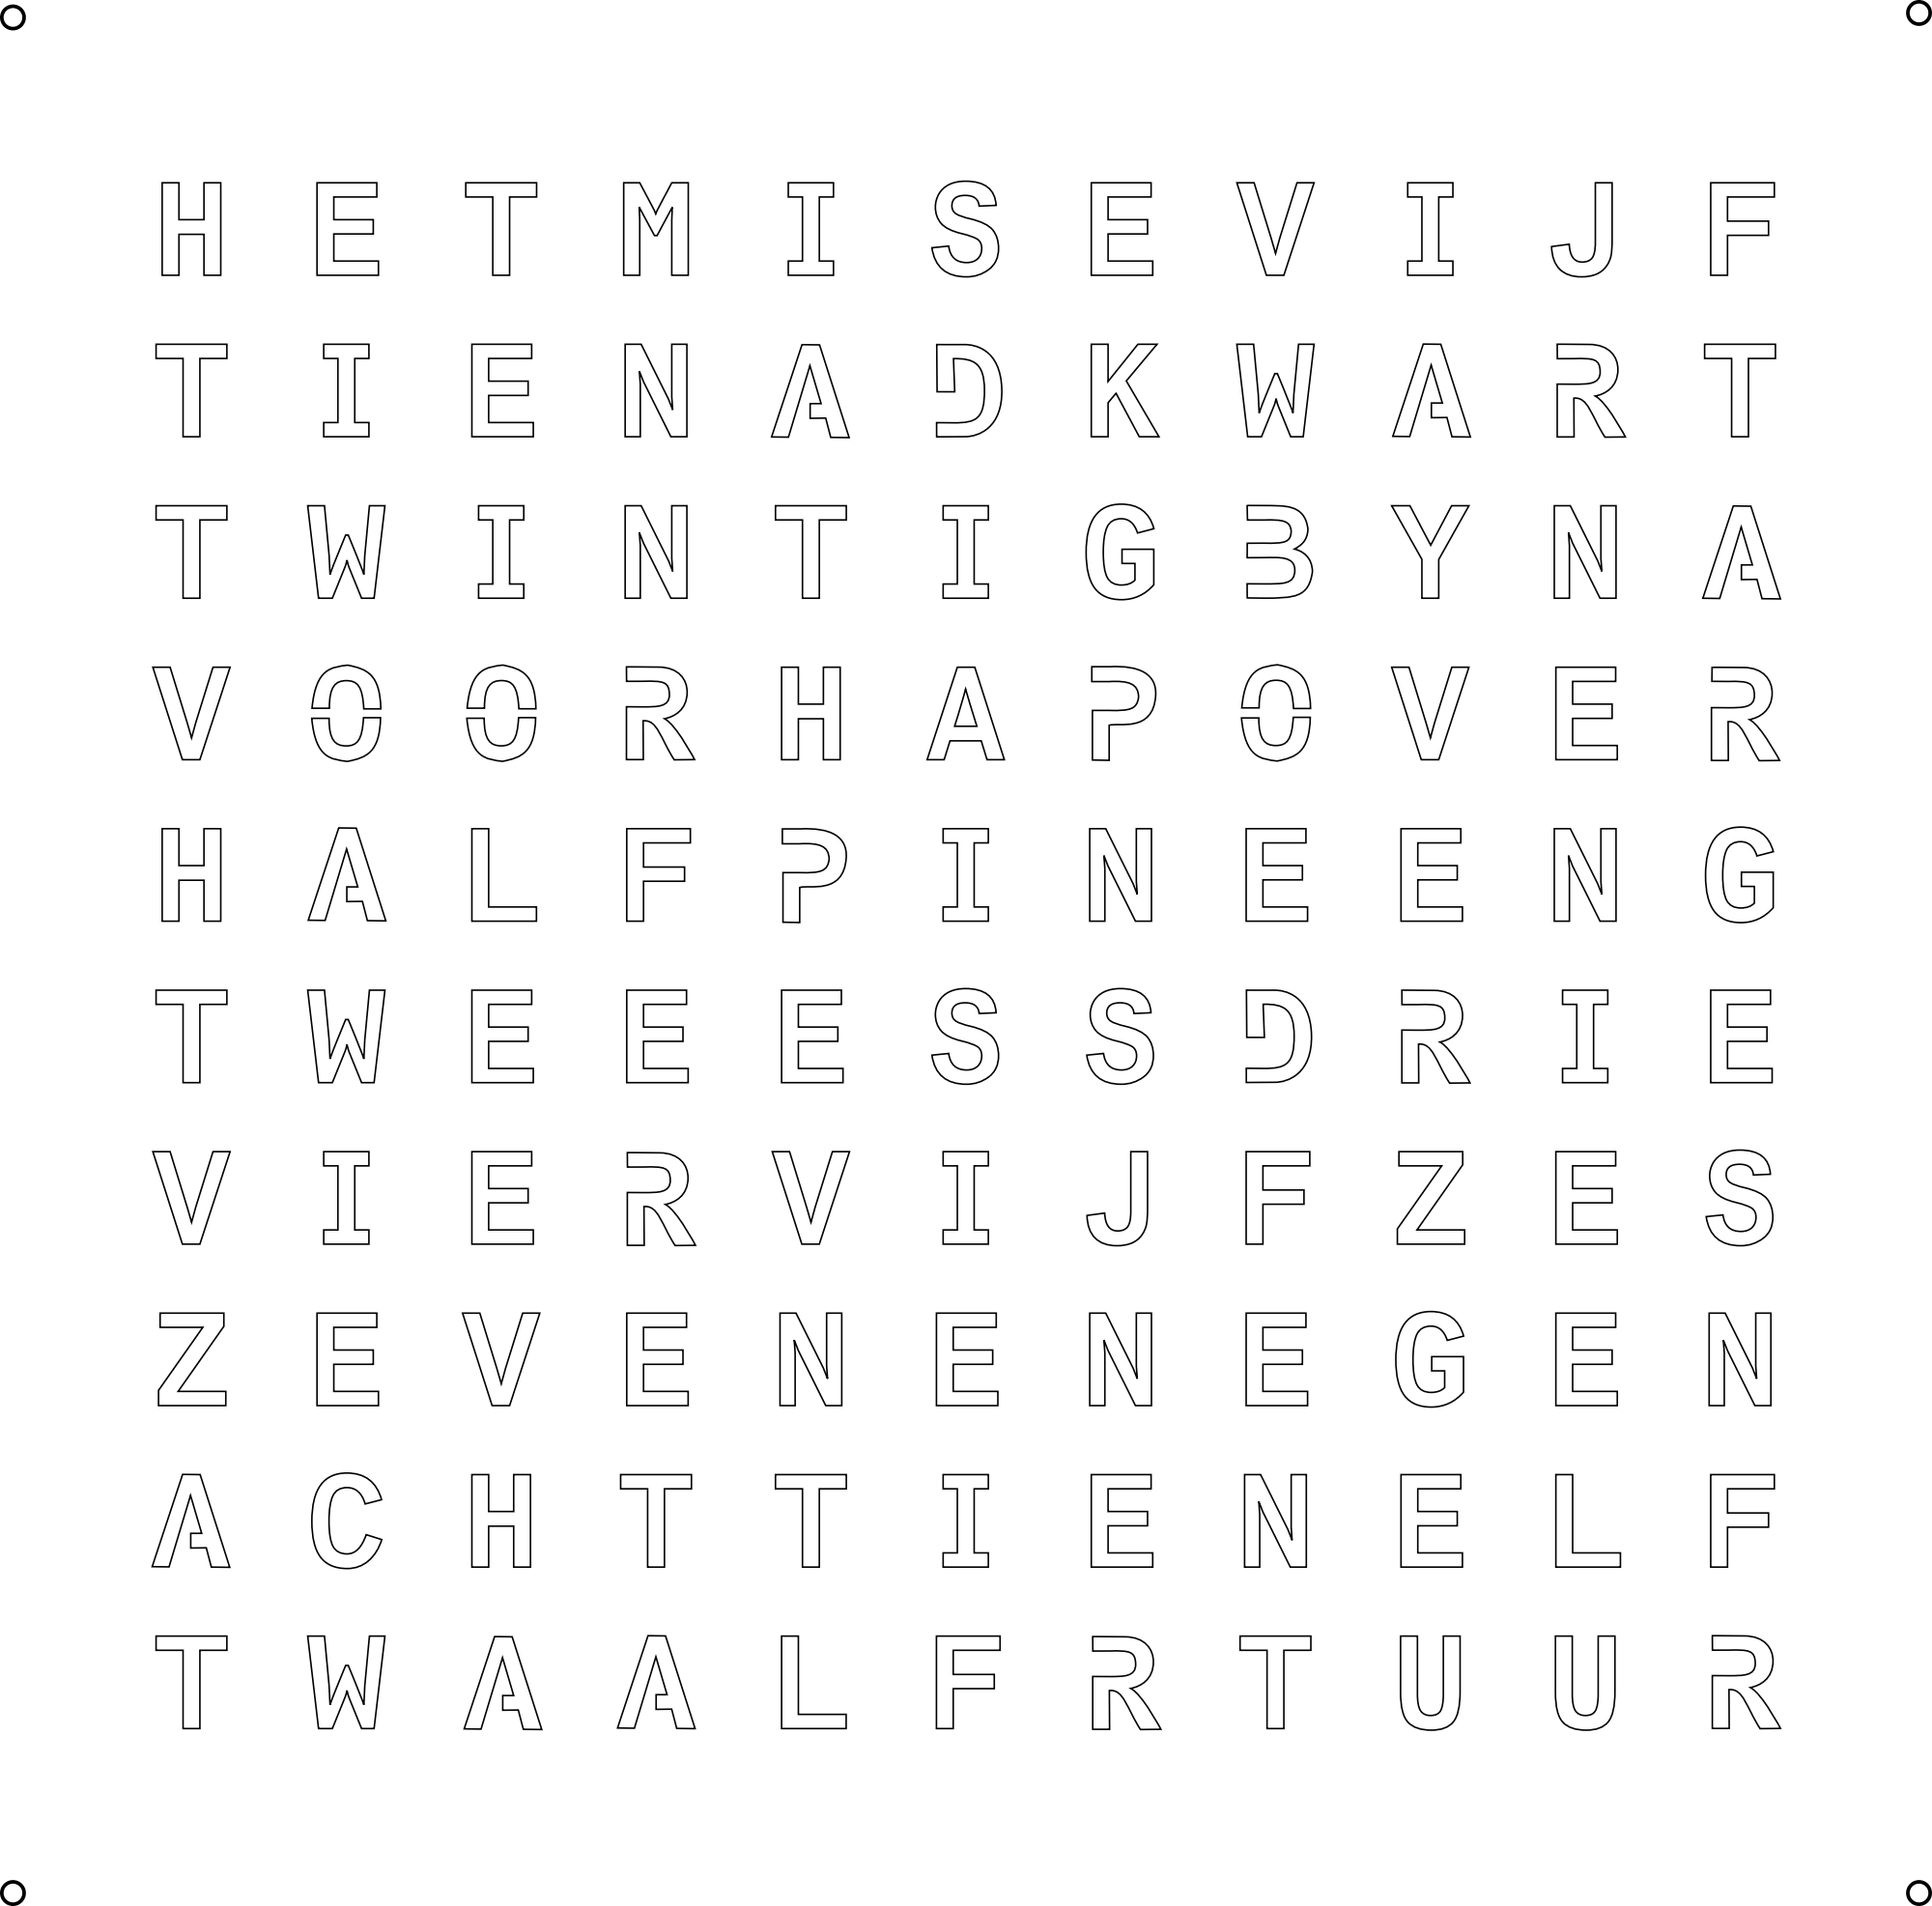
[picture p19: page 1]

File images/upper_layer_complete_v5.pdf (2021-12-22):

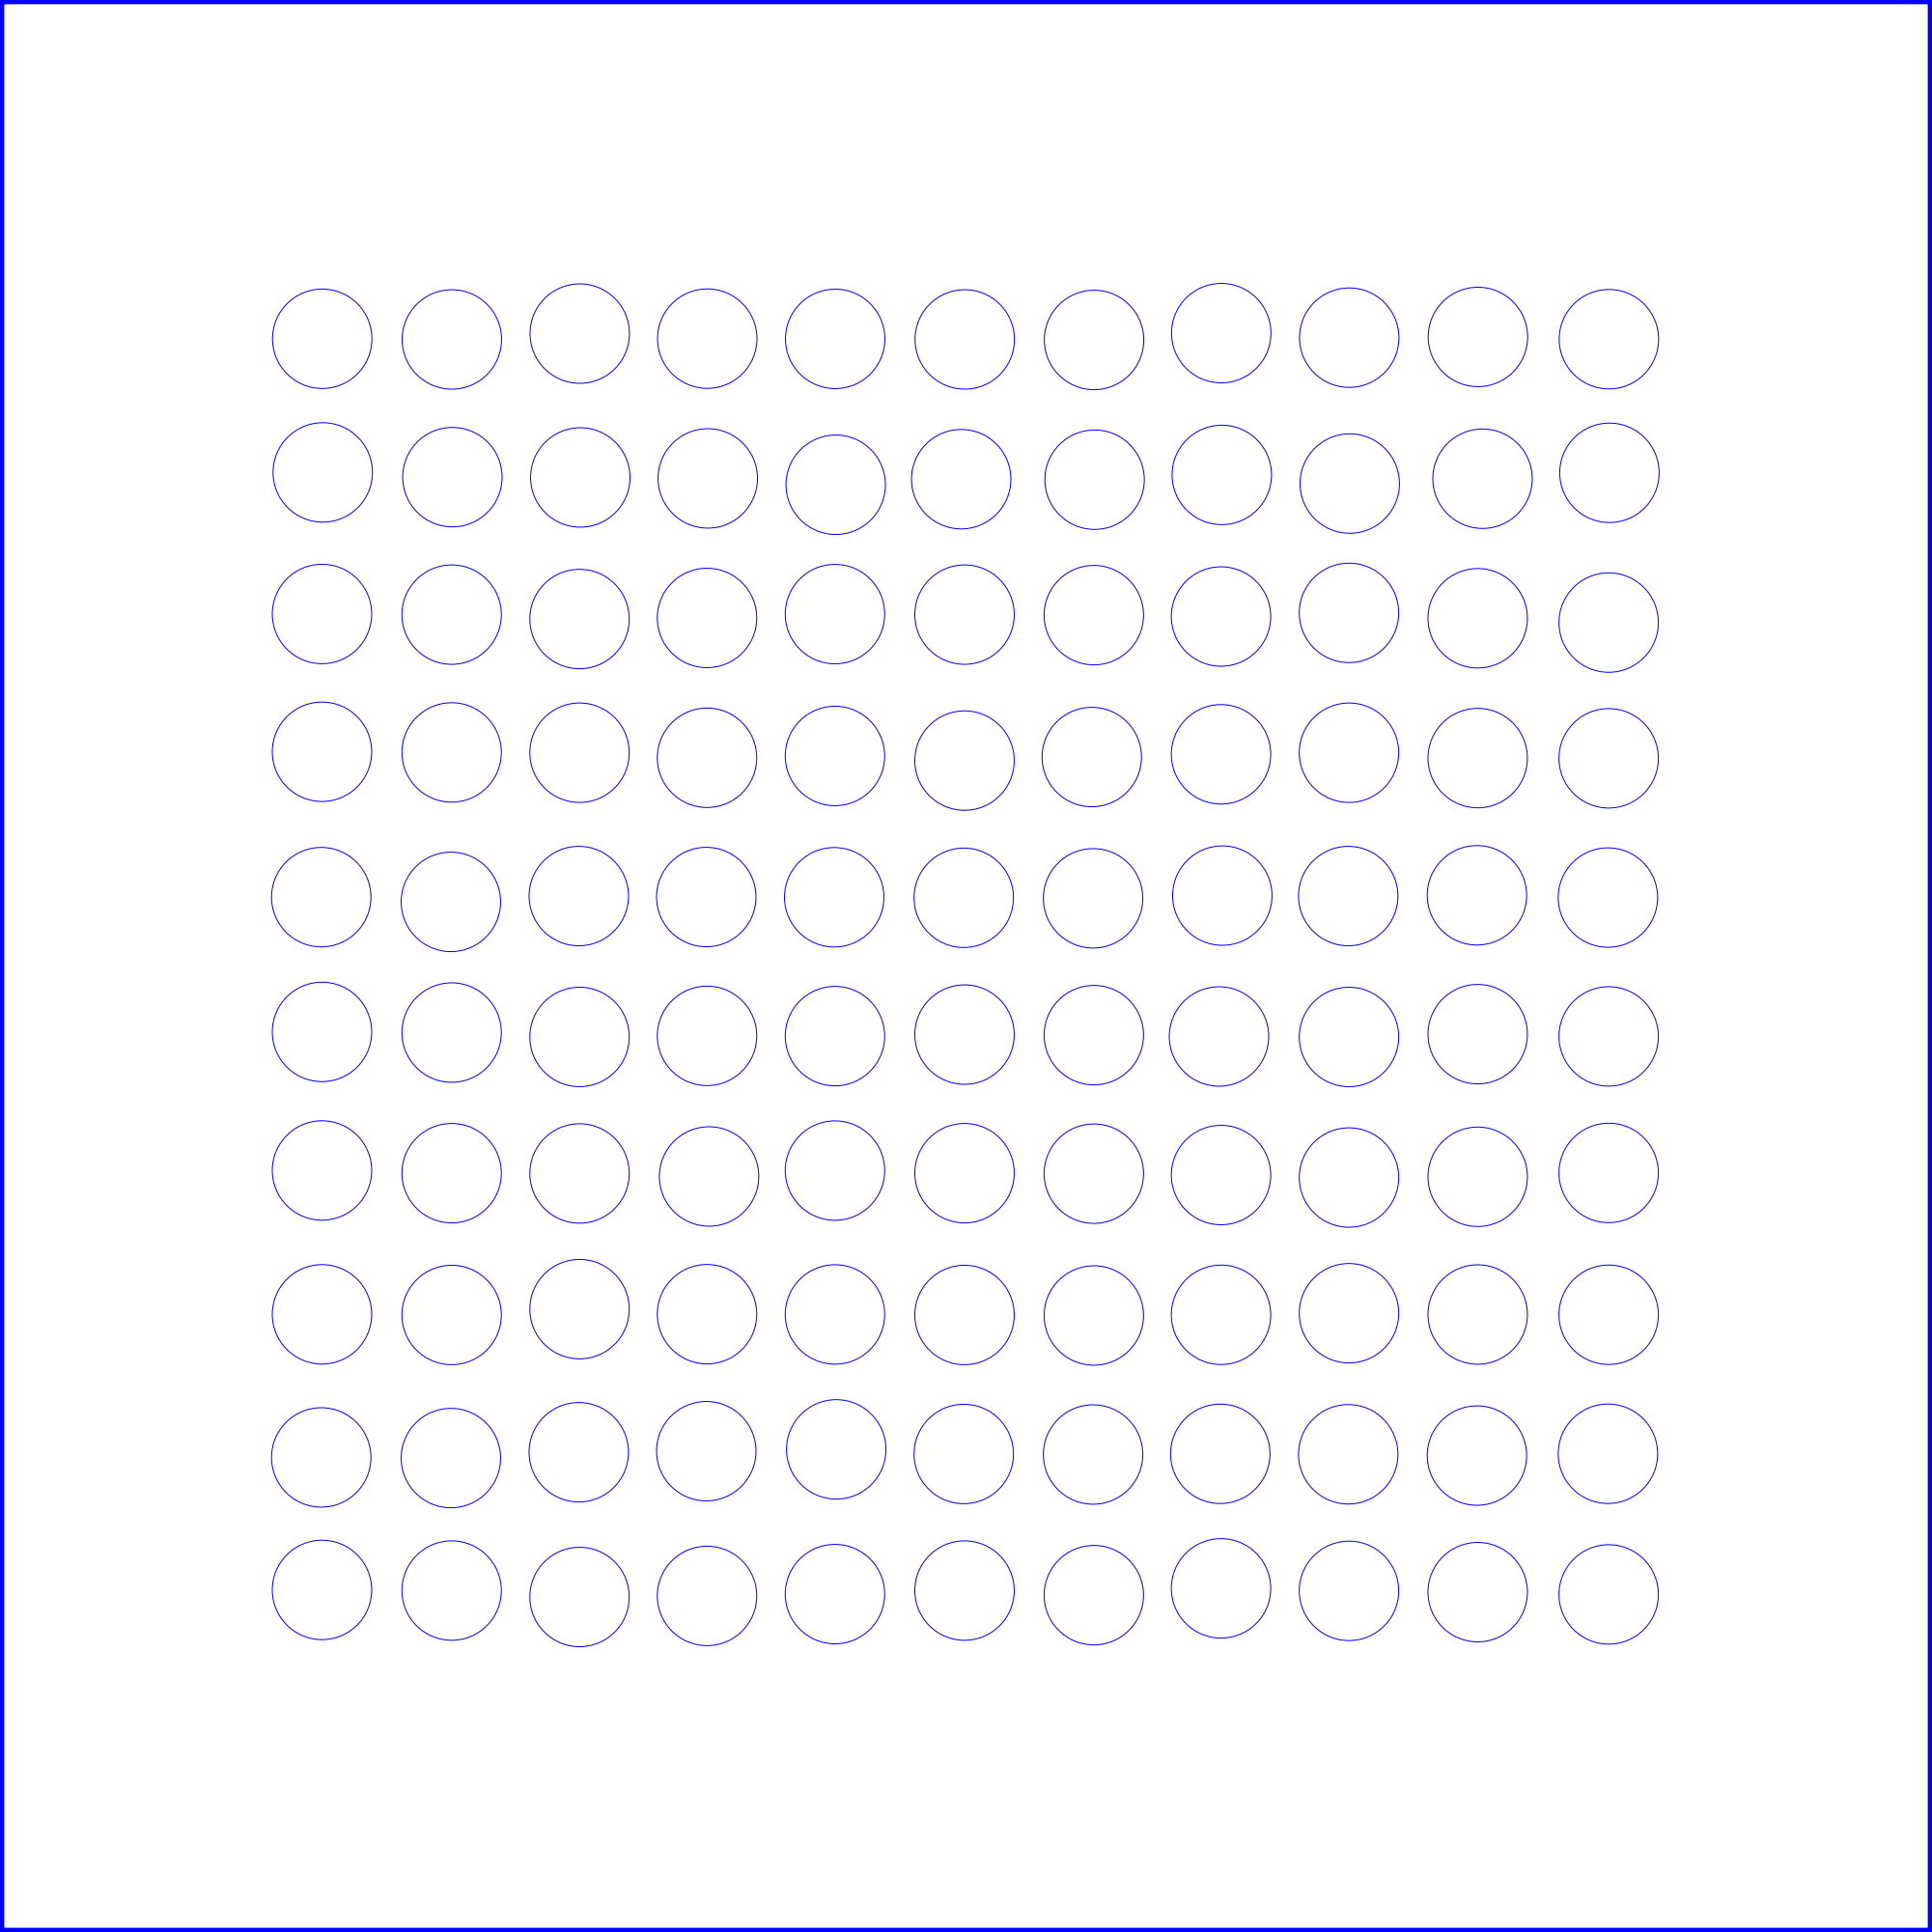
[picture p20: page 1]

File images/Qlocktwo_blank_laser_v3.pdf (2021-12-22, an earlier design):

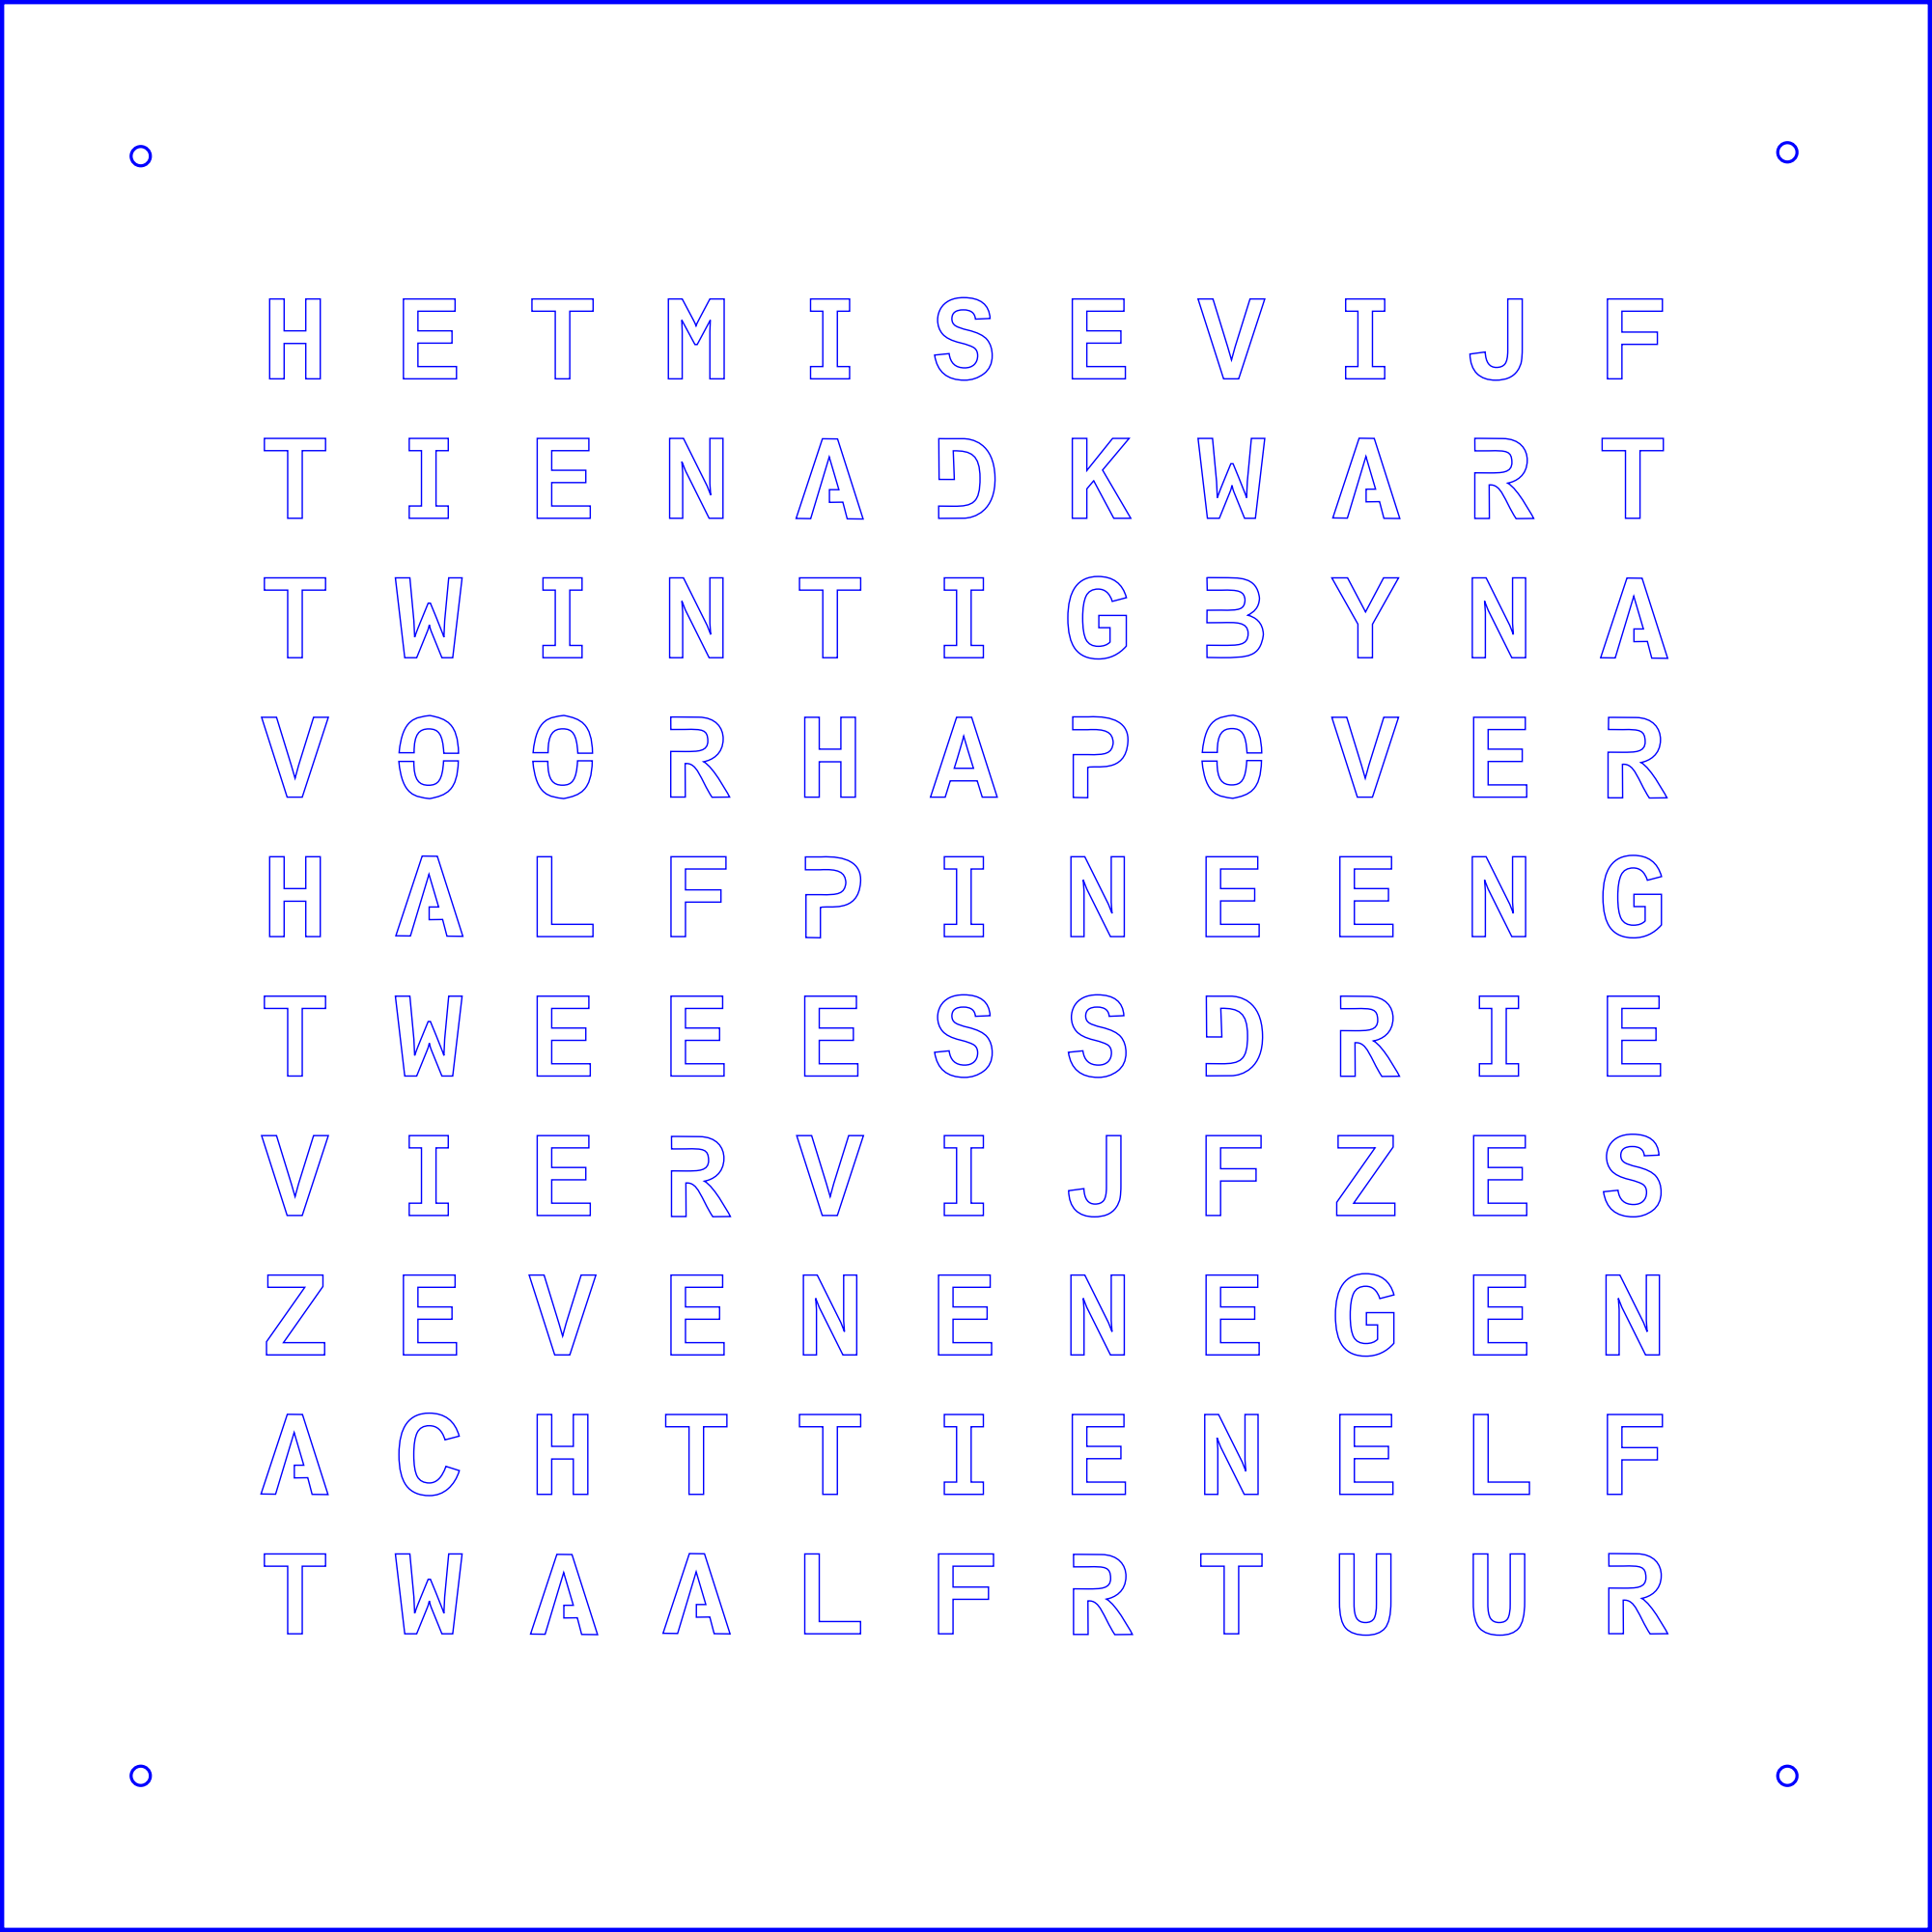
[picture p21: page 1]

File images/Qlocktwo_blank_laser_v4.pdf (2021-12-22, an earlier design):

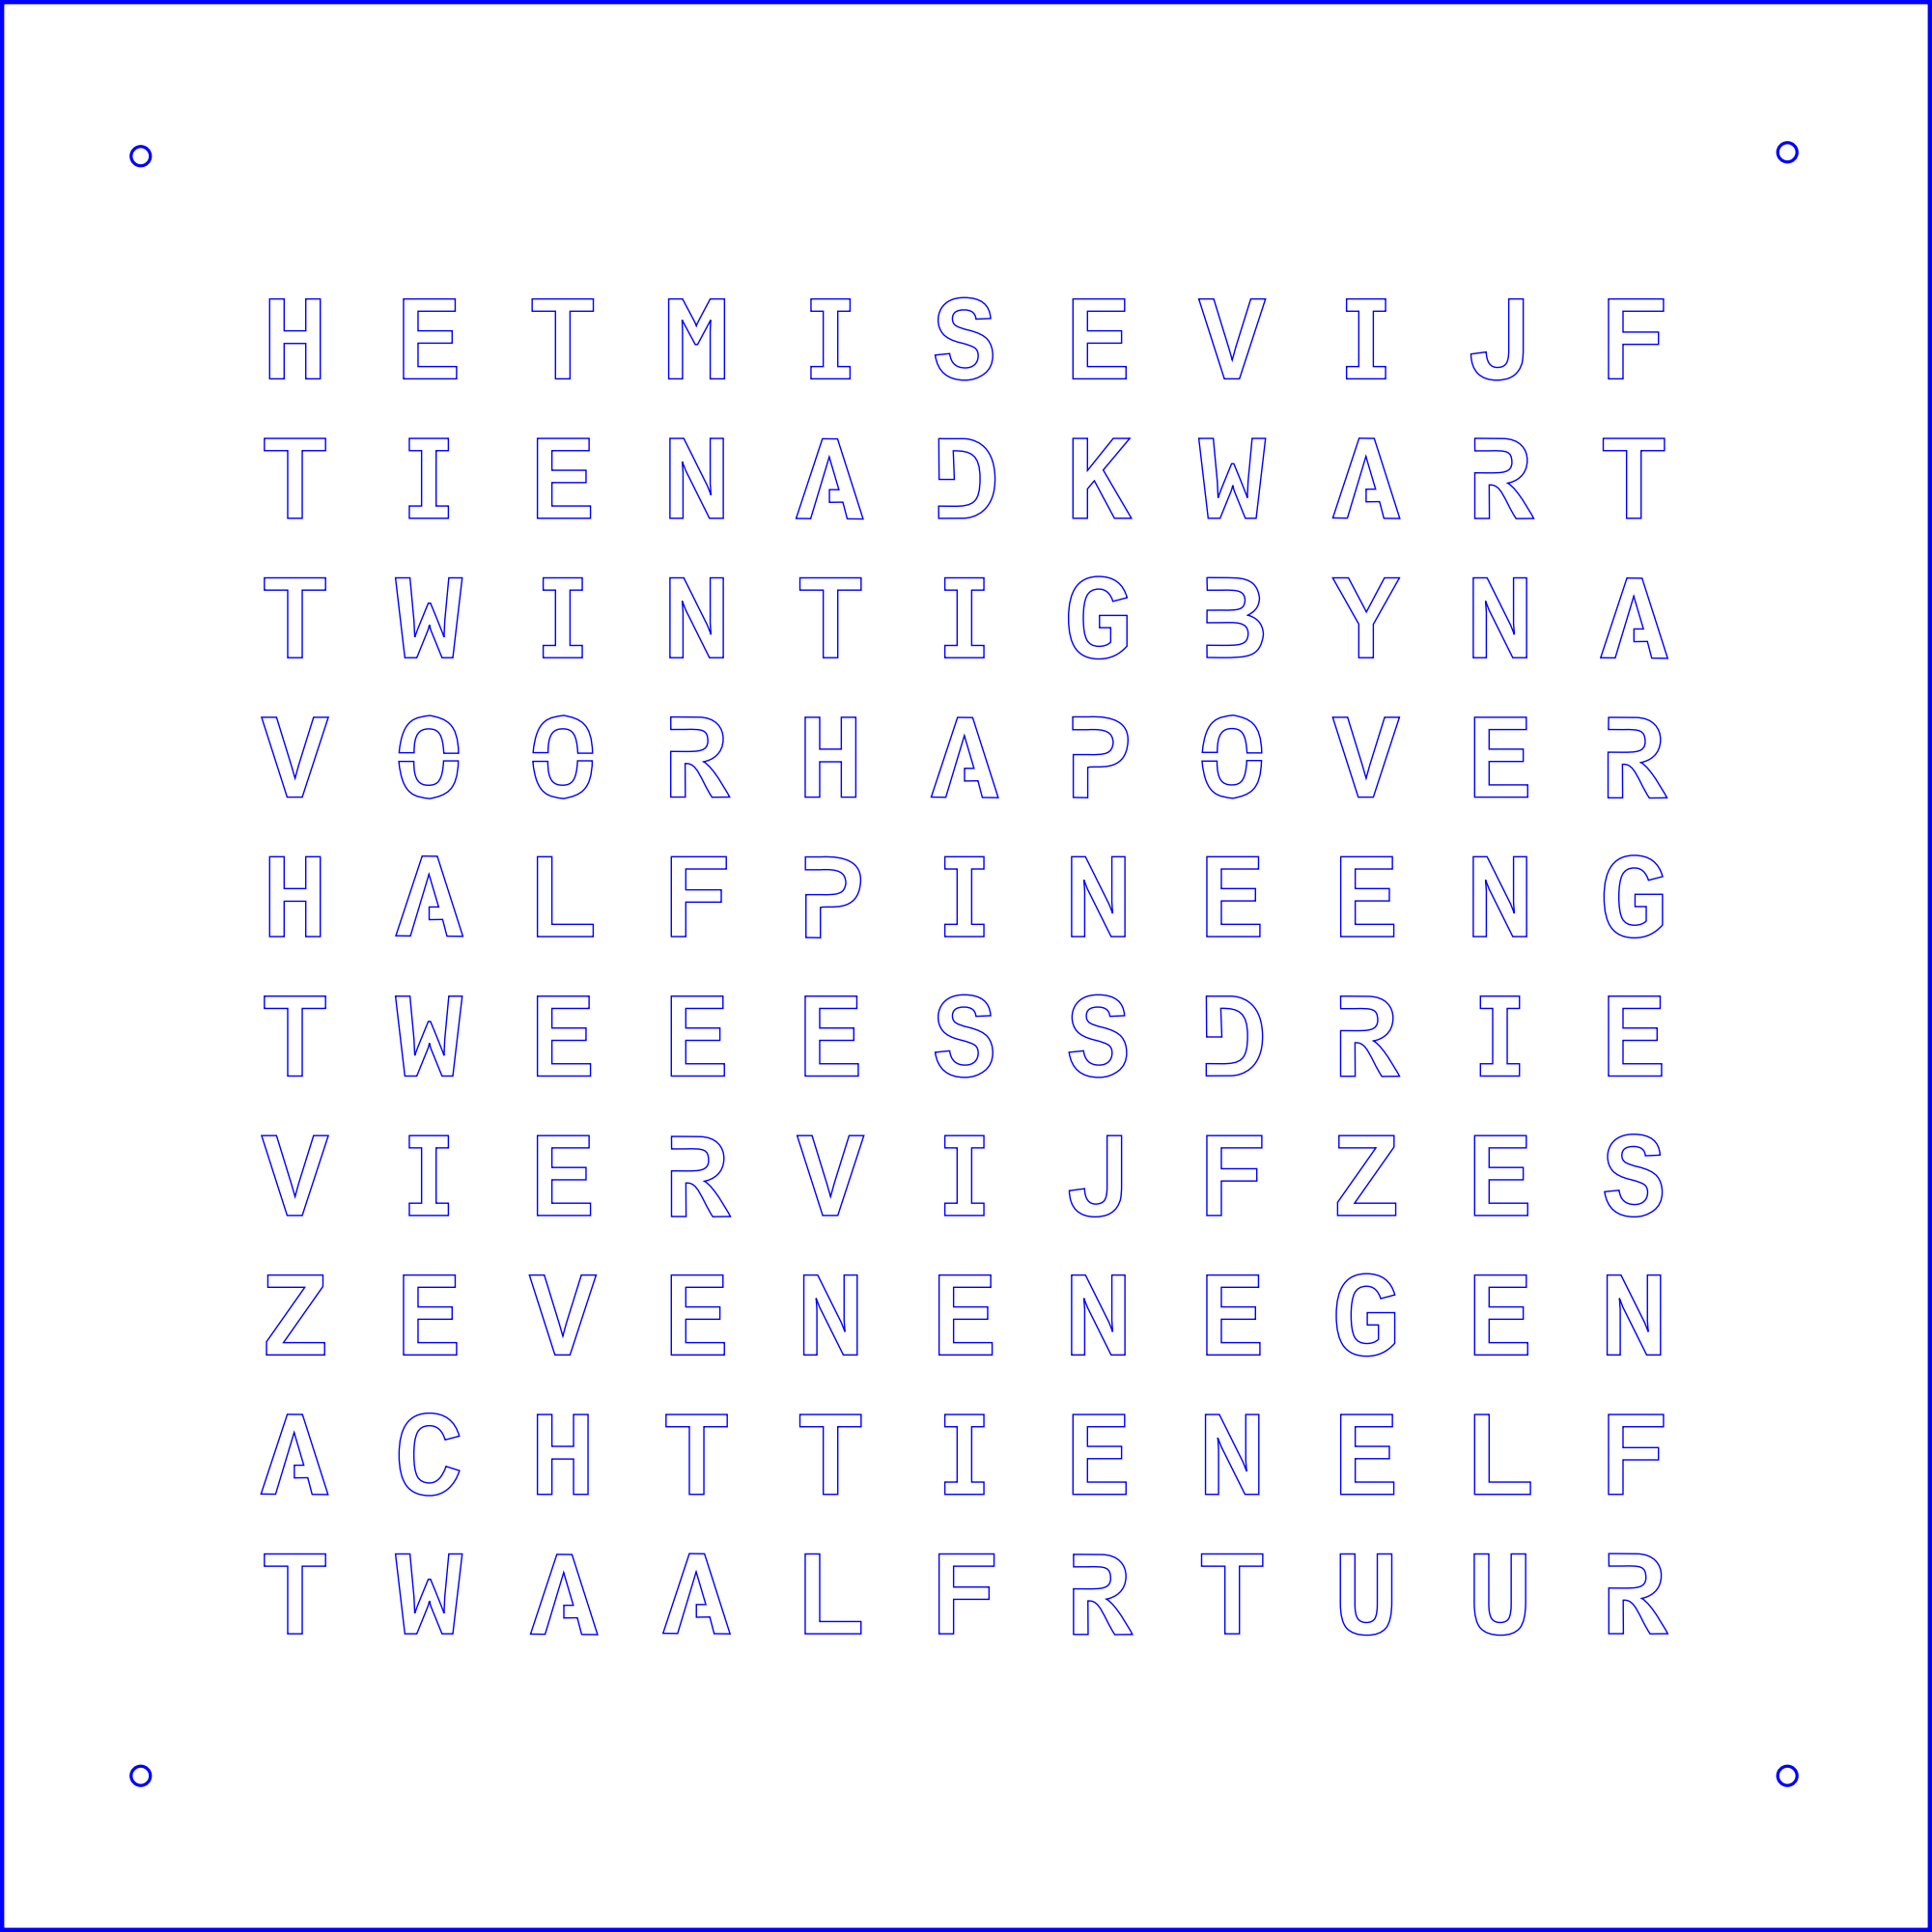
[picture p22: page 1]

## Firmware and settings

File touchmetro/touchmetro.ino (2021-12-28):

// Clock
#include <Wire.h>
#include <DS3231.h>

DS3231 clock;
RTCDateTime dt;

// Buttons
#include <AceButton.h>

using namespace ace_button;

#define BUTTON_ONE_PIN 2
#define BUTTON_TWO_PIN 0
#define BUTTON_THREE_PIN 4
#define BUTTON_FOUR_PIN 3

// Photocell
#define lightPin A0

#define NEOPIN 5

AceButton buttonOne(new ButtonConfig(),BUTTON_ONE_PIN, 1);
AceButton buttonTwo(new ButtonConfig(),BUTTON_TWO_PIN, 1);
AceButton buttonThree(new ButtonConfig(),BUTTON_THREE_PIN, 1);
AceButton buttonFour(new ButtonConfig(),BUTTON_FOUR_PIN, 1);

void setButtonConfig(ButtonConfig *buttonConfig, ButtonConfig::EventHandler eventHandler);

void handleButtonOneEvent(AceButton *, uint8_t, uint8_t);
void handleButtonTwoEvent(AceButton *, uint8_t, uint8_t);
void handleButtonThreeEvent(AceButton *, uint8_t, uint8_t);
void handleButtonFourEvent(AceButton *, uint8_t, uint8_t);

// Buttons
void setupButtons();


// Color
#include <NeoPixelBus.h>
HsbColor current_color(0, 1, 0);

// Function that selects and updates the current_color and the color_index
HsbColor adjust_color(int update);

// User Interface
enum menu_mode
{
  main_mode = 0,
  clock_mode = 1,
  brightness_mode = 2,
  config_mode = 3,
  rgb_mode = 4,
  happiness_mode = 5,
  debug_mode = 6
};
enum submenu_mode {
  clock_hour,
  clock_5min,
  clock_min,
  set_high,
  set_low,
  set_hue,
  set_sat 
};
menu_mode current_mode = menu_mode::main_mode;
submenu_mode sub_mode;

#define ITIS_CONFIG 0x01
#define TWENTY_CONFIG 0x02
#define OVER_CONFIG 0x04
#define SECONDS_CONFIG 0x08
#define DOT_CONFIG 0x10
#define BLACKLIGHT_CONFIG 0x20
#define SETCLOCK_CONFIG 0x40
#define SECONDSBAR_CONFIG 0x80
byte config = ITIS_CONFIG | TWENTY_CONFIG;

enum brightness
{
  high,
  low,
  automatic
};

// const float step = exp( log(255) / 10);
// #define step 1.7404198104793391
// const float step = exp( log(255) / 9);
#define step 1.8509443151142613
#define MAX_BRIGHTNESS 9
#define LRD_SCALE 128
int brightness_high = MAX_BRIGHTNESS;
int brightness_low = 0;
brightness current_brightness = brightness::automatic;

#define TIMEOUT 60000 // in milliseconds
#define TIME_UPDATE_INTERVAL 250 // in milli seconds
#define CLOCK_UPDATE_INTERVAL 250 // in milli seconds
#define BLINK_INTERVAL 500 // in milli seconds

unsigned long last_press = 0;
unsigned long last_change = 0;
unsigned long lastClockUpdate = 0;
unsigned long lastShowTime = 0;

//-----------------------------------------------------
// Function Declarations
//-----------------------------------------------------
void update_display();

void show_seconds();
void show_bar();
void show_hue();
void show_debug(int seconds);

void toggle_brightness();
void change_brightness(int update);
void toggle_rgb();

void change_hour(int h, int m5, int m, bool s);

void restore_settings();
void store_settings();

//
// Word Clock
//
// #include <Adafruit_NeoPixel.h>

class LedWord {
  public:
    LedWord(int firstPixelX, int firstPixelY, int length) : firstPixelX(firstPixelX), firstPixelY(firstPixelY), length(length) {}
  public:
    int firstPixelX;
    int firstPixelY;
    int length;
};

#define PREFIX_IT LedWord(0, 0, 3)
#define PREFIX_IS LedWord(4, 0, 2)

#define MINUTE_FIVE LedWord(7, 0, 4)
#define MINUTE_TEN LedWord(0, 1, 4)

#define INFIX_BEFORE LedWord(0, 3, 4)
#define INFIX_AFTER LedWord(7, 3, 4)

#define INFIX_AFTER2 LedWord(9, 2, 2)
#define MINUTE_TWENTY LedWord(0, 2, 7)
  
#define MINUTE_QUARTER LedWord(6, 1, 5)
#define MINUTE_HALF LedWord(0, 4, 4)

#define LED_ONE    LedWord(7, 4, 3)
#define LED_TWO    LedWord(0, 5, 4)
#define LED_THREE  LedWord(7, 5, 4)
#define LED_FOUR   LedWord(0, 6, 4)
#define LED_FIVE   LedWord(4, 6, 4)
#define LED_SIX    LedWord(8, 6, 3)
#define LED_SEVEN  LedWord(0, 7, 5)
#define LED_EIGHT  LedWord(0, 8, 4)
#define LED_NINE   LedWord(6, 7, 5)
#define LED_TEN    LedWord(4, 8, 4)
#define LED_ELEVEN LedWord(8, 8, 3)
#define LED_TWELVE LedWord(0, 9, 6)

#define SUFFIX_OCLOCK LedWord(8, 9, 3)

#define LED_OFFSET 0 // Normally 1
#define LED_ROW 13
#define NR_LEDS 133 // Normally 134
NeoPixelBus<NeoGrbFeature, Neo800KbpsMethod> strip(NR_LEDS, NEOPIN);

// ----------------------------------------------------
// Arduino
// ----------------------------------------------------

void setup()
{
  Serial.begin(9600);

  strip.Begin();
  strip.Show(); // Initialize all pixels to 'off'

  // Some example procedures showing how to display to the pixels:
  colorWipe(RgbColor(0, 0, 255), 2); // Red

  Serial.println("Initialize RTC module");
  
  // Initialize DS3231
  clock.begin();

  Serial.println("Setup Buttons");
  setupButtons();

  // Manual (YYYY, MM, DD, HH, II, SS
  // clock.setDateTime(2016, 12, 9, 11, 46, 00);

  // Send sketch compiling time to Arduino
  // clock.setDateTime(__DATE__, __TIME__);


  update_display();

  restore_settings();
  Serial.println("Initialization done");
}

// Fill the dots one after the other with a color
void colorWipe(RgbColor c, uint8_t wait) {
  Serial.println("colorWipe");
  HsbColor color(0, 1, 0.25);
  for (uint16_t i = 0; i < strip.PixelCount(); i++) {
    color.H = (float)i / (float)strip.PixelCount();
    strip.SetPixelColor(i, color);
    strip.Show();
    delay(wait);
  }
  delay(1000 * (long)wait);
}

#define nr_led_colors 11
HsbColor adjust_color(int update, bool sat = false) {
  if (sat) {
    int sat = round(current_color.S * (nr_led_colors-1));
    sat = sat + update;
    sat = min(nr_led_colors-1,max(0, sat));
    current_color.S = sat / (nr_led_colors-1.0f);
  }
  else {
    int hue = round(current_color.H * nr_led_colors);
    hue = hue + update;
    if (abs(update) == 1) {
      hue = min(nr_led_colors-1,max(0,hue));
    }
    else {
      if (hue > nr_led_colors-1) {
          hue = hue - nr_led_colors;
      }
      if (hue < 0) {
          hue = nr_led_colors + hue;
      }
    }
    current_color.H = (float)hue / nr_led_colors;
  }
  Serial.print("update_color ");
  Serial.println(current_color.H);
  return current_color;
}

void loop()
{
  // We need continuous updates for interactive modes
  switch (current_mode) {
    case clock_mode:
    case brightness_mode:
    case rgb_mode:
    case config_mode:
      lastClockUpdate = 0;
      lastShowTime = 0;
      break;
  }

  unsigned long current_time = millis();
  int scale = config & SECONDS_CONFIG ? 1 : 4;
  if ((current_time - lastClockUpdate) > (CLOCK_UPDATE_INTERVAL * scale) || last_press > lastClockUpdate) {
    // For leading zero look to DS3231_dateformat example
    dt = clock.getDateTime();
    lastClockUpdate = current_time;
  }

  if ( last_change != 0 && current_time > (last_change + TIMEOUT) ) {
    store_settings();
    last_change = 0;
  }

  switch (current_mode)
  {
    case brightness_mode:
      if (last_press != 0 && current_time > (last_press + TIMEOUT) )
      {
        Serial.print("Timeout ");
        Serial.print(current_time);
        Serial.print(" ");
        Serial.println(last_press);
        current_brightness = automatic;
        current_mode = main_mode;
        last_press = 0;
      }
      break;
    case happiness_mode:
    case rgb_mode:
    case config_mode:
    case debug_mode:
      if (last_press != 0 && current_time > (last_press + TIMEOUT) )
      {
        Serial.print("Timeout ");
        Serial.print(current_time);
        Serial.print(" ");
        Serial.println(last_press);
        current_mode = main_mode;
        last_press = 0;
      }
      break;
    case clock_mode:
      if (last_press != 0 && current_time > (last_press + 2 * TIMEOUT) )
      {
        Serial.print("Timeout ");
        Serial.print(current_time);
        Serial.print(" ");
        Serial.println(last_press);
        current_mode = main_mode;
        last_press = 0;
      }
      break;
  }

  if ((current_time - lastShowTime) > (TIME_UPDATE_INTERVAL * scale) || last_press > lastShowTime) {
    update_display();
    lastShowTime = current_time;
  }

  buttonOne.check();
  buttonTwo.check();
  buttonThree.check();
  buttonFour.check();
  
  delay(2);
}

/**
   Setup Event Handlers of a Button
   @param buttonConfig
   @param eventHandler
*/
void setButtonConfig(ButtonConfig *buttonConfig, ButtonConfig::EventHandler eventHandler)
{
  buttonConfig->setEventHandler(eventHandler);
  buttonConfig->setFeature(ButtonConfig::kFeatureClick);
  buttonConfig->setFeature(ButtonConfig::kFeatureDoubleClick);
  buttonConfig->setFeature(ButtonConfig::kFeatureLongPress);
  // buttonConfig->setFeature(ButtonConfig::kFeatureRepeatPress);
  buttonConfig->setClickDelay(500);
}

/**
   Setup all Buttons.
*/
void setupButtons()
{
  pinMode(BUTTON_ONE_PIN, INPUT);
  pinMode(BUTTON_TWO_PIN, INPUT);
  pinMode(BUTTON_THREE_PIN, INPUT);
  pinMode(BUTTON_FOUR_PIN, INPUT);

  setButtonConfig(buttonOne.getButtonConfig(), handleButtonOneEvent);
  setButtonConfig(buttonTwo.getButtonConfig(), handleButtonTwoEvent);
  setButtonConfig(buttonThree.getButtonConfig(), handleButtonThreeEvent);
  setButtonConfig(buttonFour.getButtonConfig(), handleButtonFourEvent);

  buttonOne.init((uint8_t)BUTTON_ONE_PIN, HIGH);
  buttonTwo.init((uint8_t)BUTTON_TWO_PIN, HIGH);
  buttonThree.init((uint8_t)BUTTON_THREE_PIN, HIGH);
  buttonFour.init((uint8_t)BUTTON_FOUR_PIN, HIGH);
}

/**
   Handle clicks of 1. button from left.
   @param button
   @param eventType
   @param buttonState
*/
void handleButtonOneEvent(AceButton *button, uint8_t eventType,
                          uint8_t buttonState)
{
  last_press = millis();
  Serial.print("Button One");
  Serial.print(eventType);
  Serial.println(buttonState);
  switch (eventType)
  {
    case AceButton::kEventClicked:
      Serial.println("Button One Clicked");
      switch (current_mode)
      {
        case main_mode:
          Serial.println("Seconds mode");
          last_change = last_press;
          config ^= SECONDS_CONFIG;
          break;
        case config_mode:
          last_change = last_press;
          config ^= ITIS_CONFIG;
          break;
        case clock_mode:
          Serial.println("decrease_clock");
          decrease_clock();
          break;
        case brightness_mode:
          Serial.println("decrease_brightness");
          last_change = last_press;
          change_brightness(-1);
          break;
        case rgb_mode:
          last_change = last_press;
          adjust_color(-1, sub_mode == set_sat);
          break;
      }
      break;
    case AceButton::kEventDoubleClicked:
      Serial.println("Button One Double clicked");
      switch (current_mode)
      {
        case main_mode:
          Serial.println("Seconds mode");
          last_change = last_press;
          config ^= SECONDS_CONFIG;
          break;
        case config_mode:
          last_change = last_press;
          config ^= ITIS_CONFIG;
          break;
        case clock_mode:
          Serial.println("decrease_clock");
          decrease_clock();
          decrease_clock();
          break;
        case brightness_mode:
          Serial.println("decrease_brightness");
          last_change = last_press;
          change_brightness(-1);
          change_brightness(-1);
          break;
        case rgb_mode:
          last_change = last_press;
          adjust_color(-1, sub_mode == set_sat);
          adjust_color(-1, sub_mode == set_sat);
          break;
      }
      break;
    case AceButton::kEventLongPressed:
      Serial.println("Button One Long Press");
      switch (current_mode)
      {
        case main_mode:
          Serial.println("From main mode to clock mode");
          current_mode = clock_mode;
          sub_mode = clock_hour;
          break;
        case config_mode:
          last_change = last_press;
          config ^= DOT_CONFIG;
          break;
      }
      break;
  }
}

/**
   Handle clicks of 2. button from left.
   @param button
   @param eventType
   @param buttonState
*/
void handleButtonTwoEvent(AceButton *button, uint8_t eventType,
                          uint8_t buttonState)
{
  last_press = millis();

  switch (eventType)
  {
    case AceButton::kEventClicked:
      Serial.println("Button Two Clicked");
      switch (current_mode) {
        case main_mode:
          last_change = last_press;
          toggle_brightness();
          break;
        case clock_mode:
          switch(sub_mode) {
            case clock_hour:
              sub_mode = clock_5min;
              break;
            case clock_5min:
              sub_mode = clock_min;
              break;
            default:
              sub_mode = clock_hour;
              break;
          }
          Serial.print("clock_mode sub_mode:");
          Serial.println(sub_mode);
          break;
        case config_mode:
           last_change = last_press;
           config ^= OVER_CONFIG;
           break;    
        case brightness_mode:
          Serial.print("switch brightness ");
          Serial.print(sub_mode);
          if (sub_mode == set_low)
          {
            sub_mode = set_high;
          }
          else
          {
            sub_mode = set_low;
          }
          Serial.print(" to ");
          Serial.println(sub_mode);
          break;
        case rgb_mode:
          if (sub_mode == set_hue)
            sub_mode = set_sat;
          else
            sub_mode = set_hue;
          break;
      }
      break;
    case AceButton::kEventDoubleClicked:
      Serial.println("Button Two Double clicked");
      switch (current_mode) {
        case clock_mode:
          switch(sub_mode) {
            case clock_hour:
              sub_mode = clock_5min;
              break;
            case clock_5min:
              sub_mode = clock_min;
              break;
            default:
              sub_mode = clock_hour;
              break;
          }
          break;
      }
      break;
    case AceButton::kEventLongPressed:
      Serial.println("Button Two Long Press");
      switch (current_mode) {
        case clock_mode:
          Serial.println("reset_seconds");
          change_hour(0,0,0,true);
          break;
        case main_mode:
          Serial.println("From main mode to brightness mode");
          current_mode = brightness_mode;
          sub_mode = set_high;
          break;
        case config_mode:
           last_change = last_press;
           config ^= TWENTY_CONFIG;
           break;    
      }
  }
}

/**
   Handle clicks of 3. button from left.
   @param button
   @param eventType
   @param buttonState
*/
void handleButtonThreeEvent(AceButton *button, uint8_t eventType,
                            uint8_t buttonState)
{
  last_press = millis();

  switch (eventType)
  {
    case AceButton::kEventClicked:
      Serial.println("Button Three Clicked");
      switch (current_mode) {
        case main_mode:
          last_change = last_press;
          toggle_rgb();
          break;
        case clock_mode:
          Serial.println("increase_clock");
          increase_clock();
          break;
        case brightness_mode:
          Serial.println("increase_brightness");
          last_change = last_press;
          change_brightness(1);
          break;
        case config_mode:
           last_change = last_press;
           config ^= BLACKLIGHT_CONFIG;
           break;    
        case rgb_mode:
          last_change = last_press;
          adjust_color(1, sub_mode == set_sat);
          break;
      }
      break;
    case AceButton::kEventDoubleClicked:
      Serial.println("Button Three Double clicked");
      switch (current_mode) {
        case main_mode:
          last_change = last_press;
          toggle_rgb();
          toggle_rgb();
          break;
        case clock_mode:
          Serial.println("increase_clock");
          increase_clock();
          increase_clock();
          break;
        case brightness_mode:
          Serial.println("increase_brightness");
          last_change = last_press;
          change_brightness(1);
          change_brightness(1);
          break;
        case rgb_mode:
          last_change = last_press;
          adjust_color(1, sub_mode == set_sat);
          adjust_color(1, sub_mode == set_sat);
          break;
      }
      break;
    case AceButton::kEventLongPressed:
      Serial.println("Button Three Long Press");
      switch (current_mode) {
        case main_mode:
          Serial.println("From main mode to rgb mode");
          current_mode = rgb_mode;
          sub_mode = set_hue;
          break;
        case clock_mode:
          // Do nothing
          break;
        case config_mode:
          last_change = last_press;
          config ^= SECONDSBAR_CONFIG;
          break;    
      }
      break;
  }
}

/**
   Handle clicks of 3. button from left.
   @param button
   @param eventType
   @param buttonState
*/
void handleButtonFourEvent(AceButton *button, uint8_t eventType,
                            uint8_t buttonState)
{
  last_press = millis();

  switch (eventType)
  {
    case AceButton::kEventClicked:
      Serial.println("Button Four Clicked");
      switch(current_mode) {
        case main_mode:
          current_mode = happiness_mode;
          break;
      }
      break;
    case AceButton::kEventDoubleClicked:
      Serial.println("Button Four Double clicked");
      switch(current_mode) {
        case happiness_mode:
          current_mode = debug_mode;
          break;
      }
      break;
    case AceButton::kEventLongPressed:
      Serial.println("Button Four Long Press");
      switch(current_mode) {
        case main_mode:
          current_mode = config_mode;
          break; 
        default:
          current_mode = main_mode;
          break;
      }
      break;
  }
}

void update_display()
{
  //Serial.print("update_display brightness: ");
  
  // First determine the brightness and color of the display
  switch (current_brightness)
  {
    case automatic:
      {
        int reading = analogRead(lightPin);
        float scale = brightness_low + max(0.0f, min(1.0f, reading / (float)LRD_SCALE)) * (brightness_high - brightness_low);
        current_color.B = pow(step, scale) / 255.0f;
      }
      break;
    case high:
      current_color.B = pow(step, brightness_high) / 255.0f; // auto_levels[auto_high] / 255.0f;
      break;
    case low:
      current_color.B = pow(step, brightness_low) / 255.0f; // auto_levels[auto_low] / 255.0f;
      break;
  }
  //Serial.println(currentcolor.B);

  switch (current_mode)
  {
    case main_mode:
      display_hour(current_color, dt.hour, dt.minute, dt.second, config);
      break;
    case config_mode:
      if (config & TWENTY_CONFIG) {
        display_hour(current_color, 12, 24, dt.second, config | SECONDS_CONFIG);        
      }
      else {
        display_hour(current_color, 12, 44, dt.second, config | SECONDS_CONFIG);        
      }
      break;
    case clock_mode:
      display_hour(current_color, dt.hour, dt.minute, dt.second, config | SETCLOCK_CONFIG | SECONDS_CONFIG);
      break;
    case rgb_mode:
      show_hue();
      break;
    case brightness_mode:
      show_bar();
      break;
    case happiness_mode:
      show_happiness(current_color);
      break;
    case debug_mode:
      show_debug(dt.second);
      break;
  }
}

void enable_led(LedWord  word, const HsbColor &color, bool display=true)
{
  if (!display) return;
  if (word.firstPixelY % 2 == 0) {
    int start_index = word.firstPixelY * LED_ROW + word.firstPixelX + LED_OFFSET;
    int i = 0;
    for (i = 0; i < word.length; i++) {
      strip.SetPixelColor(start_index + i, color);
    }
  } else {
    int start_index = word.firstPixelY * LED_ROW + 10 - word.firstPixelX + LED_OFFSET;
    for (int i = 0; i < word.length; ++i) {
      strip.SetPixelColor(start_index - i, color);
    }
  }
}

void enableMinuteDots(int minute, const HsbColor &color, byte config)
{
   int minuteDots = minute % 5;
   if (config & DOT_CONFIG) {
      //Serial.print("enableMinuteDots ");
      //Serial.println(minuteDots);
      if (minuteDots > 0) 
        strip.SetPixelColor(NR_LEDS-3, color);
      if (minuteDots > 1) 
        strip.SetPixelColor(NR_LEDS-2, color);
      if (minuteDots > 2) 
        strip.SetPixelColor(NR_LEDS-1, color);
      if (minuteDots > 3) 
        strip.SetPixelColor(NR_LEDS-4, color);
   }
   
}

void show_bar()
{
  bool blink =  ((millis() / BLINK_INTERVAL) % 2) == 0;
  HsbColor currentcolor = current_color;
  strip.ClearTo(RgbColor(0, 0, 0));
  if (sub_mode != set_low or blink) {
    currentcolor.B = pow(step, brightness_low) / 255.0f;
    enable_led(LedWord(0, brightness_low, 10-brightness_low), currentcolor);
  }  
  for(int i=brightness_low+1; i<brightness_high; ++i) {
    currentcolor.B = pow(step, i) / 255.0f;
    enable_led(LedWord(0, i, 10-i), currentcolor);
  }
  if (sub_mode != set_high or blink) {
    currentcolor.B = pow(step, brightness_high) / 255.0f;
    enable_led(LedWord(0, brightness_high, 10-brightness_high), currentcolor);
  }  
  strip.Show();
}
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

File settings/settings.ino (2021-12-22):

// include the library code:
#include <LiquidCrystal_74HC595.h>

// - Original code from the tutorial
// initialize the library with the numbers of the interface pins
// LiquidCrystal lcd(7, 8, 9, 10, 11, 12);
//
// - New code to support LiquidCrystal with 74HC595
LiquidCrystal_74HC595 lcd(11, 13, 12, 1, 3, 4, 5, 6, 7);

// Clock
#include <Wire.h>
#include <DS3231.h>

DS3231 clock;
RTCDateTime dt;

// Buttons
#include <AceButton.h>

using namespace ace_button;

#define BUTTON_ONE_PIN 2
#define BUTTON_TWO_PIN 3
#define BUTTON_THREE_PIN 4

AceButton buttonOne(new ButtonConfig());
AceButton buttonTwo(new ButtonConfig());
AceButton buttonThree(new ButtonConfig());

// Buttons
void setupButtons();
void setButtonConfig(ButtonConfig *buttonConfig, ButtonConfig::EventHandler eventHandler);

void handleButtonOneEvent(AceButton *, uint8_t, uint8_t);
void handleButtonTwoEvent(AceButton *, uint8_t, uint8_t);
void handleButtonThreeEvent(AceButton *, uint8_t, uint8_t);

// Photocell
const int lightPin = A1;

// Led
const int greenLEDPin = 9;
const int redLEDPin = 6;
const int blueLEDPin = 10;

// Color
#include <NeoPixelBus.h>
const HsbColor led_colors[] = {
     HsbColor(0, 1, 1),
     HsbColor(0, 0.8, 1),
     HsbColor(0.125, 0.8, 1),
     HsbColor(0.125, 1, 1),
     HsbColor(0.25, 1, 1),
     HsbColor(0.25, 0.8, 1),
     HsbColor(0.375, 0.8, 1),
     HsbColor(0.375, 1, 1),
     HsbColor(0.5, 1, 1),
     HsbColor(0.5, 0.8, 1),
     HsbColor(0.5, 0, 1),
     HsbColor(0.625, 0.8, 1),
     HsbColor(0.625, 1, 1),
     HsbColor(0.75, 1, 1),
     HsbColor(0.75, 0.8, 1),
     HsbColor(0.875, 0.8, 1),
     HsbColor(0.875, 1, 1)
};
int color_index = 0;
const int nr_led_colors = 16;

// User Interface
enum menu_mode
{
    main_mode = 0,
    clock_mode = 1,
    brightness_mode = 2,
    seconds_mode = 3
};
menu_mode current_mode = menu_mode::main_mode;
bool it_is = true;

enum brightness
{
    very_high = 255,
    high = 153,
    medium = 91,
    low = 55,
    very_low = 33,
    automatic = -1,
    set_high = -2,
    set_low = -3
};
int auto_levels[16];
int auto_high = 15;
int auto_low = 3;
brightness current_brightness = brightness::automatic;

const long TIMEOUT = 10000; // in milliseconds
const long TIME_UPDATE_INTERVAL = 1; // in seconds
const long CLOCK_UPDATE_INTERVAL = 1; // in seconds

unsigned long last_press = 0;
unsigned long last_change = 0;
unsigned long lastClockUpdate = 0;
unsigned long lastShowTime = 0;


//-----------------------------------------------------
// Function Declarations
//-----------------------------------------------------

void update_display();
void show_hour();
void show_seconds();
void show_bar();

void toggle_brightness();
void increase_brightness(brightness high_or_low);
void decrease_brightness(brightness high_or_low);
void toggle_rgb();

void increase_hour();
void decrease_hour();
void increase_5min();
void decrease_5min();
void increase_1min();
void decrease_1min();

void restore_settings();
void store_settings();

// LCD utilities
void lcd_print_time(int col, int row, int hour);
void lcd_print_hour(int col, int row, int hour);

// ----------------------------------------------------
// Arduino
// ----------------------------------------------------

void setup()
{
    Serial.begin(9600);

   float step = pow(0.6, 1.0/ 3.0);

    for(int i=0; i<16; i++) {
        Serial.print(i);
        Serial.print(' ');
        Serial.print(step);
        Serial.print(' ');
        auto_levels[15-i] = (int)(255.0f * pow(step, i));
        Serial.println(auto_levels[15-i]);
    }


    // set up the LCD's number of columns and rows:
    lcd.begin(16, 2);

    Serial.println("Initialize RTC module");

    // Initialize DS3231
    clock.begin();

    setupButtons();

    // Manual (YYYY, MM, DD, HH, II, SS
    // clock.setDateTime(2016, 12, 9, 11, 46, 00);

    // Send sketch compiling time to Arduino
    // clock.setDateTime(__DATE__, __TIME__);

    pinMode(greenLEDPin, OUTPUT);
    pinMode(redLEDPin, OUTPUT);
    pinMode(blueLEDPin, OUTPUT);

    restore_settings();
    
    update_display();
}

void loop()
{
    // We need continuous updates for interactive modes
    switch(current_mode) {
    case clock_mode:
        lastClockUpdate = 0;
        lastShowTime = 0;
        break;
    }

    unsigned long current_time = millis();
    if((current_time - lastClockUpdate) > (CLOCK_UPDATE_INTERVAL * 1000) || last_press > lastClockUpdate) {
        // For leading zero look to DS3231_dateformat example
        dt = clock.getDateTime();
        lastClockUpdate = millis();
    }

    if ( last_change != 0 && current_time > (last_change + TIMEOUT) ) {
      store_settings();
      last_change = 0;
    }

    switch (current_mode)
    {
    case brightness_mode:
    case clock_mode:
        if (last_press != 0 && current_time > (last_press + TIMEOUT) )
        {
            if (current_mode == brightness_mode) {
                current_brightness = automatic;
            }

            Serial.print("Timeout ");
            Serial.print(current_time);
            Serial.print(" ");
            Serial.println(last_press);
            lcd.clear();
            current_mode = main_mode;
            last_press = 0;

        }
        break;
    }

    if((millis() - lastShowTime) > (TIME_UPDATE_INTERVAL * 1000) || last_press > lastShowTime) {
        update_display();
        lastShowTime = millis();
    }


    buttonOne.check();
    buttonTwo.check();
    buttonThree.check();

    // delay(2);
}

/**
 * Setup Event Handlers of a Button
 * @param buttonConfig
 * @param eventHandler
 */
void setButtonConfig(ButtonConfig *buttonConfig, ButtonConfig::EventHandler eventHandler)
{
    buttonConfig->setEventHandler(eventHandler);
    buttonConfig->setFeature(ButtonConfig::kFeatureClick);
    buttonConfig->setFeature(ButtonConfig::kFeatureDoubleClick);
    buttonConfig->setFeature(ButtonConfig::kFeatureLongPress);
    // buttonConfig->setFeature(ButtonConfig::kFeatureRepeatPress);
}

/**
 * Setup all Buttons.
 */
void setupButtons()
{
    pinMode(BUTTON_ONE_PIN, INPUT);
    buttonOne.init(BUTTON_ONE_PIN, LOW);

    pinMode(BUTTON_TWO_PIN, INPUT);
    buttonTwo.init(BUTTON_TWO_PIN, LOW);

    pinMode(BUTTON_THREE_PIN, INPUT);
    buttonThree.init(BUTTON_THREE_PIN, LOW);

    setButtonConfig(buttonOne.getButtonConfig(), handleButtonOneEvent);
    setButtonConfig(buttonTwo.getButtonConfig(), handleButtonTwoEvent);
    setButtonConfig(buttonThree.getButtonConfig(), handleButtonThreeEvent);
}
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

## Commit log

2021-03-31 User interface
    [userinterface.fzz]
2021-04-05 Color wheel
    [userinterface.fzz]
2021-12-22 Commit before removing seconds bar
    [userinterface.fzz]
2021-12-28 First website
    [touchmetro_rev2_contour.gm1, touchmetro_rev2_copperBottom.gbl, touchmetro_rev2_copperTop.gtl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]
